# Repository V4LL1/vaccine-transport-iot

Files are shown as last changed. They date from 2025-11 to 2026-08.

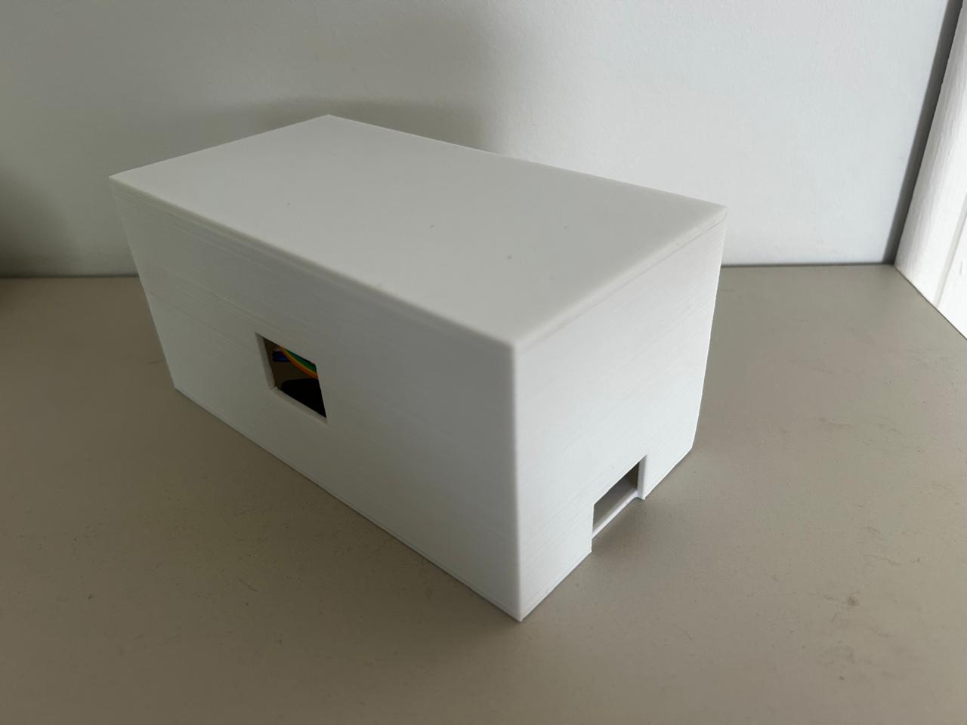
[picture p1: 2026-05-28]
diagrams/TG2/imagems/caixa 3d com componentes.jpeg

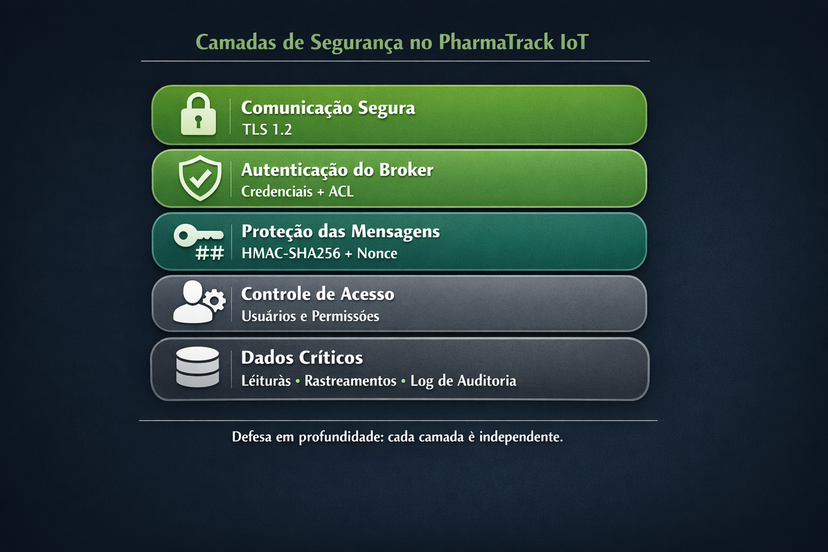
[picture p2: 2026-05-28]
diagrams/TG2/imagems/Copilot_figura3 .png

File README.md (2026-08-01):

IoT-based pharmaceutical cold chain monitoring system built with ESP32, Python (Flask), MySQL, and MQTT over TLS. Features real-time temperature, humidity, and GPS tracking, RBAC, MFA, HMAC message signing, audit logging, and a live dashboard for secure, low-cost pharmaceutical transport monitoring.

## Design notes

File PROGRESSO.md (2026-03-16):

# Registro de Progresso — TCC IoT Vaccine Transport

## Como usar este arquivo
A cada sessão de trabalho, registre aqui o que foi concluído.
Isso serve como ponto de retomada entre sessões.

---

## MILESTONE 1 — Pipeline MQTT Funcional ✅ CONCLUÍDO (2026-03-12)

### O que foi implementado

#### ESP32 — `source/esp32/main/main.ino`
- [x] WiFi com reconexão automática (baseado em `hardware/test_wifi/test_wifi.ino`)
- [x] MQTT via `PubSubClient` conectado ao broker local
- [x] Payload JSON com `ArduinoJson` (`StaticJsonDocument<256>`)
- [x] Publicação de leituras a cada **5 segundos** no tópico `vaccines/readings`
- [x] Heartbeat a cada **30 segundos** no tópico `vaccines/heartbeat`
- [x] Campos `hmac` e `nonce` presentes no payload (vazios — prontos para M2)
- [x] Timestamp UTC via GPS (`gps.date` + `gps.time`)
- [x] `#define MQTT_MAX_PACKET_SIZE 512` configurado
- IP configurado: `10.0.0.175` | Device: `IOT-GPS-004` | Trip: `3`

#### Flask — `source/app/app.py`
- [x] Thread background `paho-mqtt` subscriber (API versão 2 — sem deprecation warning)
- [x] `on_message`: normaliza timestamp ISO 8601 → formato MySQL, grava em `readings`
- [x] `on_message`: atualiza `devices.last_seen` ao receber heartbeat ou leitura
- [x] Novo endpoint `GET /api/alarms` — leituras fora do range da vacina
- [x] Novo endpoint `GET /api/devices` — status online/offline por último heartbeat
- [x] Novo endpoint `GET /api/status` — estado do broker MQTT + último timestamp
- [x] Endpoint `/api/trips` atualizado com `min_temp` e `max_temp`
- [x] Endpoint `/api/readings/recent` atualizado com thresholds da vacina

#### Dashboard — `source/app/templates/index.html`
- [x] Refresh automático a cada **5 segundos**
- [x] Badge MQTT (verde = conectado / vermelho = desconectado) no header
- [x] Painel de alarmes: lista violações de temperatura com batch code e tipo
- [x] Leituras em vermelho (⚠) quando fora do range da vacina
- [x] Status dos dispositivos: cards coloridos (online/recente/offline/nunca)
- [x] Informações de threshold da viagem selecionada

#### Banco de Dados — `source/database/db_script.sql`
- [x] Tabela `audit_log` criada (log de ações do sistema — rastreabilidade)
- [x] Tabela `seen_nonces` criada (anti-replay — será usada no M2)
- [x] Coluna `totp_secret VARCHAR(32)` adicionada em `users` (para M2 — MFA)
- [x] Senhas de seed substituídas por hashes bcrypt reais

#### Broker — `source/broker/mosquitto.conf`
- [x] Configuração básica: porta 1883, acesso anônimo (desenvolvimento)
- [x] Criado em `source/broker/mosquitto.conf`

#### Dependências — `source/app/requirements.txt`
- [x] Arquivo criado com versões fixas: `flask`, `mysql-connector-python`, `paho-mqtt`
- [x] Libs de M2 listadas em comentário (bcrypt, pyotp, flask-login, cryptography)

### Como subir o ambiente (após reinicialização)

```bash
# 1. Iniciar MySQL (sem senha, datadir customizado)
"C:\Program Files\MySQL\MySQL Server 8.0\bin\mysqld.exe" --datadir="C:/Users/guilh/mysql-data" --port=3306

# 2. Iniciar Mosquitto
"C:\Program Files\mosquitto\mosquitto.exe" -c "source/broker/mosquitto.conf"

# 3. Iniciar Flask
cd source/app
../../venv/Scripts/python.exe app.py

# Para recriar o banco do zero:
"C:\Program Files\MySQL\MySQL Server 8.0\bin\mysql.exe" -u root < source/database/db_script.sql
```

### Verificação end-to-end M1
```bash
# Publicar leitura de teste (temperatura dentro do range Spikevax: -25°C a -15°C)
"C:\Program Files\mosquitto\mosquitto_pub.exe" -h 127.0.0.1 -p 1883 -t "vaccines/readings" \
  -m '{"device_id":"IOT-GPS-004","trip_id":3,"timestamp":"2026-03-12T18:00:00Z","temperature":-20.0,"humidity":60.0,"latitude":-23.21,"longitude":-45.88,"satellites":8,"hmac":"","nonce":""}'

# Verificar no banco
"C:\Program Files\MySQL\MySQL Server 8.0\bin\mysql.exe" -u root --batch -e "SELECT COUNT(*) FROM vaccine_transport.readings;"

# Verificar status
curl http://127.0.0.1:5000/api/status
```

---

## MILESTONE 2 — Camada de Segurança ⏳ PENDENTE

### O que precisa ser feito

#### Certificados TLS (openssl)
- [ ] Gerar CA self-signed
- [ ] Gerar certificado do broker assinado pela CA
- [ ] Criar pasta `certs/` com CA, broker.crt, broker.key

#### Mosquitto TLS — `source/broker/mosquitto-tls.conf`
- [ ] Configurar porta 8883 com TLS
- [ ] Configurar `cafile`, `certfile`, `keyfile`
- [ ] Criar `passwd` file com credenciais dos dispositivos (`mosquitto_passwd`)
- [ ] Criar `acl_file` por device_id
- [ ] Desativar porta 1883 (apenas 8883)

#### ESP32 — `source/esp32/main/main.ino`
- [ ] Trocar `WiFiClient` por `WiFiClientSecure`
- [ ] Adicionar CA cert como string PROGMEM
- [ ] `wifiClientSecure.setCACert(CA_CERT)`
- [ ] Calcular HMAC-SHA256 do payload com chave do NVS
  - Usar `mbedtls_md_hmac` (disponível no ESP32)
  - Chave armazenada via `Preferences.h` (`preferences.putBytes("hmac_key", ...)`)
- [ ] Gerar nonce com `esp_random()` (hex 8 bytes = 16 chars)
- [ ] Mudar porta para 8883
- [ ] Adicionar usuário/senha MQTT (`mqttClient.connect(id, user, pass)`)

#### Flask — `source/app/app.py`
- [ ] Verificação HMAC-SHA256 em `on_message`
- [ ] Deduplicação de nonce (INSERT em `seen_nonces`, rejeitar duplicata)
- [ ] Verificação de janela de timestamp (rejeitar msg com timestamp > 5min atrás)
- [ ] Instalar e configurar `Flask-Login`
- [ ] Rota `GET/POST /login` com verificação bcrypt
- [ ] Verificação TOTP (`pyotp.TOTP(user.totp_secret).verify(token)`)
- [ ] Decorator `@login_required` em todas as rotas
- [ ] RBAC: decorator `@admin_required` para rotas admin
- [ ] paho-mqtt com TLS (`client.tls_set(ca_certs=...)`)
- [ ] Novo template `source/app/templates/login.html`

#### Banco
- [ ] Nenhuma migration necessária (tabelas `seen_nonces` e coluna `totp_secret` já existem)

---

## MILESTONE 3 — Proteção de Dados + Continuidade ⏳ PENDENTE

- [ ] AES-256-GCM em Python antes de INSERT (colunas temp, humidity, lat, lng)
- [ ] Chave AES em `.env` (`python-dotenv`)
- [ ] Script `source/scripts/backup.sh` (mysqldump + gpg symmetric)
- [ ] Buffer SPIFFS no ESP32 (`/buffer.jsonl`) para mensagens offline
- [ ] Reconexão automática com flush do buffer (QoS 1)
- [ ] Script `source/scripts/cleanup_nonces.py` (limpeza de nonces > 10min)
- [ ] Hardware: circuito de redundância de energia (TP4056 + LiPo 18650)

---

## MILESTONE 4 — Dashboard Completo + Alertas ⏳ PENDENTE

- [ ] Server-Sent Events (SSE) em vez de polling
- [ ] Painel de alarmes com botão ACK (registra em `audit_log`)
- [ ] Alerta por email via `smtplib` (gmail app password)
- [ ] Geração de PDF de viagem (`reportlab`)
- [ ] Viewer de `audit_log` (admin only)
- [ ] Página admin com gestão de usuários e dispositivos

---

## MILESTONE 5 — Failover + Documentação Final ⏳ PENDENTE

- [ ] `docker-compose.yml` com dois Mosquitto (8883 + 8884)
- [ ] ESP32: lógica de troca para broker secundário após 3 falhas
- [ ] Flask: dois threads paho-mqtt (primary + secondary), mesmo DB
- [ ] Documento SOP: rotação de certificados (`docs/sop-cert-rotation.md`)
- [ ] Documento SOP: restauração de backup (`docs/sop-backup-restore.md`)
- [ ] README final com diagrama de arquitetura atualizado

---

## Notas Técnicas Importantes

| Assunto | Detalhe |
|---|---|
| MySQL sem senha | Inicializado com `--initialize-insecure`. Datadir: `C:/Users/guilh/mysql-data` |
| MySQL sem serviço Windows | Precisa iniciar manualmente a cada boot (ver comando acima) |
| Mosquitto path | `C:\Program Files\mosquitto\mosquitto.exe` |
| Python venv | `source/venv/Scripts/python.exe` |
| Senha admin dashboard | `admin123` (bcrypt no banco) |
| Senha operadores | `op123` (bcrypt no banco) |
| Viagem ativa (M1) | Trip ID 3 — Spikevax Moderna, device IOT-GPS-004 |
| Range temp. Spikevax | -25°C a -15°C (testar com temperatura nesse range) |
| Payload MQTT M1 | Campos `hmac` e `nonce` presentes mas vazios |

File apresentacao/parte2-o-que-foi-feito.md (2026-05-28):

# PARTE 2 — O QUE FOI CONSTRUÍDO

---

## 2.1 Visão Geral da Arquitetura

O sistema foi construído em três milestones principais, com desenvolvimento incremental e testado em cada etapa antes de avançar.

**Milestone 1 (M1)** — Pipeline funcional: ESP32 → MQTT → Flask → MySQL → Dashboard. Sistema operacional sem segurança avançada, foco em validar o fluxo de dados de ponta a ponta.

**Milestone 2 (M2)** — Camada de segurança: TLS 1.2, autenticação MQTT, MFA, RBAC, HMAC, nonce, audit log. Sistema com segurança em produção.

**Milestone 3 (M3)** — Dashboard completo + multi-tenancy: sistema multi-empresa, gestão completa de dispositivos/rastreamentos/usuários, mapa global de todos os rastreamentos, tab de debug, dados ricos de demonstração.

O desenvolvimento seguiu o princípio de **security by design** — cada componente foi projetado com segurança como requisito desde o início, não como adição posterior.

---

## 2.2 Hardware — A Camada de Percepção

### O Dispositivo

O dispositivo físico é construído sobre o **ESP32 DevKit V1**, um microcontrolador da Espressif Systems com as seguintes características relevantes para este projeto:

- **Processador**: Xtensa LX6 dual-core, 240 MHz
- **Memória**: 520KB SRAM, 4MB Flash
- **Conectividade**: WiFi 802.11 b/g/n, Bluetooth 4.2
- **Criptografia**: Acelerador de hardware para AES, SHA, RSA (utilizado pelo `mbedtls`)
- **Custo**: ~R$30 no mercado brasileiro

A escolha do ESP32 sobre alternativas como Arduino Uno ou Raspberry Pi foi deliberada:
- WiFi nativo (sem shield adicional)
- Suporte a TLS via `WiFiClientSecure` e `mbedtls`
- Acelerador criptográfico em hardware (HMAC-SHA256 sem sobrecarregar a CPU)
- Sistema de arquivos SPIFFS para buffer offline
- Watchdog Timer por hardware via IDF

### Sensores Integrados

#### DHT22 — Temperatura e Umidade
- **Pino**: GPIO 4
- **Faixa de temperatura**: -40°C a +80°C (precisão ±0.5°C)
- **Faixa de umidade**: 0% a 100% (precisão ±2%)
- **Protocolo**: Single-wire (1-Wire customizado)
- **Taxa de amostragem**: 1 leitura a cada 2 segundos (mínimo do sensor)
- **Tratamento de falha**: `isnan(temp)` → valor 0.0 no payload (evita travamento)
- **Biblioteca**: `DHT sensor library` (Adafruit)

O DHT22 foi escolhido sobre o DHT11 pela precisão significativamente superior (±0.5°C vs ±2°C) — crítico para produtos com faixas estreitas como Spikevax (-25°C a -15°C, janela de apenas 10°C).

#### GPS NEO-6M — Localização
- **Interface**: UART1 (GPIO 16 RX, GPIO 17 TX)
- **Baudrate**: 9600 bps
- **Protocolo**: NMEA 0183 (sentença GPRMC, GPGGA)
- **Precisão**: ±2.5m (CEP, sem SBAS)
- **Tempo de fix frio**: ~30s em campo aberto
- **Biblioteca**: TinyGPS++ (parser eficiente em memória)

A biblioteca TinyGPS++ foi escolhida pela eficiência — processa bytes NMEA individualmente (`gps.encode(c)`) sem alocar strings grandes, adequado para a RAM limitada do ESP32.

**Validação GPS**: antes de usar as coordenadas, o firmware verifica `gps.location.isValid()`. Se o fix ainda não foi adquirido, envia `latitude: 0.0, longitude: 0.0` — o dashboard distingue esses valores de coordenadas reais.

### A Caixa 3D

A caixa do dispositivo foi modelada do zero no **OpenSCAD** — uma linguagem de programação para modelagem 3D sólida, ideal para designs paramétricos.

**Dimensões**: 170 × 90 × 80mm (externas)
**Material**: PLA (impressão FDM)
**Espessura de parede**: 2.5mm

**Características de design**:
- Abertura frontal (USB/alimentação): 27 × 18mm — cobre o conector Micro-B com margem para plugues angulados
- Abertura lateral (DHT22): 29 × 21mm — sensor voltado para o ambiente externo para leitura correta
- 3 furos de ventilação (Ø7mm): na parede oposta ao USB, para circulação de ar
- Tampa removível: encaixe por plug de 3mm de profundidade com folga de 0.15mm por lado (0.3mm total) — calibrado para impressão FDM

O projeto passou por iteração com o estabelecimento de impressão 3D: a primeira versão tinha o lip interno de encaixe que impossibilitava o fechamento. A versão final usa encaixe direto nas paredes internas da caixa, sem saliências.

---

## 2.3 Firmware — A Lógica do Dispositivo

O firmware foi desenvolvido em **C++ com Arduino Framework** na Arduino IDE, com as seguintes bibliotecas:

| Biblioteca | Versão | Função |
|---|---|---|
| PubSubClient | 2.8 | Cliente MQTT |
| ArduinoJson | 6.x | Serialização JSON |
| DHT sensor library | 1.4.x | Leitura DHT22 |
| TinyGPS++ | 1.0.x | Parser NMEA GPS |
| WiFiClientSecure | (ESP32 built-in) | TLS sobre WiFi |
| mbedtls | (ESP32 built-in) | HMAC-SHA256 |
| SPIFFS | (ESP32 built-in) | Buffer offline |
| esp_task_wdt | (ESP32 IDF) | Watchdog timer |

### 2.3.1 Estrutura do Firmware

O firmware é organizado em módulos funcionais dentro de um único arquivo `main.ino`:

```
setup()
  ├── Serial.begin(115200)
  ├── SPIFFS.begin()              ← monta filesystem
  ├── configureWatchdog()         ← inicializa WDT 60s
  ├── WiFi.begin(SSID, PASS)
  ├── syncNTP()                   ← sincroniza relógio
  └── connectMQTT()

loop()
  ├── esp_task_wdt_reset()        ← alimenta watchdog
  ├── processGPS()                ← lê bytes UART
  ├── ensureWiFi()                ← reconecta se necessário
  ├── ensureMQTT()                ← reconecta + flushBuffer()
  ├── mqttClient.loop()           ← processa ACKs
  ├── a cada 5s: publishReading() ← ou saveToBuffer()
  └── a cada 30s: publishHeartbeat()
```

### 2.3.2 Payload JSON

Cada mensagem de leitura tem a seguinte estrutura:

```json
{
  "device_id":   "ESP32-A1B2C3D4E5F6",
  "timestamp":   "2026-03-15T18:45:30Z",
  "temperature": -20.5,
  "humidity":    65.3,
  "latitude":    -23.550520,
  "longitude":   -46.633309,
  "satellites":  12,
  "hmac":        "a3f2c1...64chars",
  "nonce":       "9f3a2b1c4d5e6f7a"
}
```

O heartbeat (a cada 30s) é mais simples:

```json
{
  "device_id": "ESP32-A1B2C3D4E5F6",
  "timestamp": "2026-03-15T18:45:30Z",
  "status":    "online"
}
```

### 2.3.3 Device ID Dinâmico

O ID do dispositivo é gerado automaticamente do endereço MAC do hardware:

```cpp
String mac = WiFi.macAddress();   // "A1:B2:C3:D4:E5:F6"
mac.replace(":", "");             // "A1B2C3D4E5F6"
DEVICE_ID_STR = "ESP32-" + mac;  // "ESP32-A1B2C3D4E5F6"
```

Isso garante unicidade por hardware, sem precisar hardcodar identificadores. Em uma frota de 100 dispositivos, cada um se auto-identifica corretamente.

### 2.3.4 Sincronização de Tempo — NTP + GPS

O timestamp preciso é fundamental para a rastreabilidade. O firmware usa uma hierarquia de fontes:

1. **GPS (prioridade máxima)**: quando a localização é válida, o GPS também fornece a hora UTC com precisão de ±1ms. Isso é importante para o mecanismo anti-replay — um timestamp muito divergente do servidor pode indicar ataque.

2. **NTP (fallback)**: se o GPS ainda não tem fix, sincroniza com `pool.ntp.org` e `time.google.com`. A sincronização é executada no boot e após cada reconexão WiFi.

3. **Timestamp vazio (último recurso)**: se ambos falharem, o campo é enviado vazio e o Flask usa `NOW()` do MySQL — mantém o dado, mas com menor precisão.

### 2.3.5 Segurança no Firmware

#### TLS com Verificação de Certificado

```cpp
WiFiClientSecure wifiClientSecure;
wifiClientSecure.setCACert(CA_CERT);  // embedded como string PROGMEM
PubSubClient mqttClient(wifiClientSecure);
mqttClient.setServer(MQTT_BROKER, 8883);
```

O certificado CA está embutido no firmware como uma string `PROGMEM` (armazenada na flash, não na RAM). O `setCACert()` instrui o stack TLS a verificar o certificado do broker contra esse CA — qualquer certificado de outra CA é rejeitado, prevenindo ataques MITM.

**Atualmente, o projeto usa o HiveMQ Cloud como broker**, que usa Let's Encrypt como CA. O firmware contém o certificado intermediário R12 da Let's Encrypt embutido.

#### HMAC-SHA256

```cpp
void computeHMAC(const char* payload, char* out) {
    uint8_t result[32];
    mbedtls_md_context_t ctx;
    mbedtls_md_init(&ctx);
    mbedtls_md_setup(&ctx, mbedtls_md_info_from_type(MBEDTLS_MD_SHA256), 1);
    mbedtls_md_hmac_starts(&ctx, (const uint8_t*)HMAC_KEY, strlen(HMAC_KEY));
    mbedtls_md_hmac_update(&ctx, (const uint8_t*)payload, strlen(payload));
    mbedtls_md_hmac_finish(&ctx, result);
    mbedtls_md_free(&ctx);
    // converte 32 bytes → 64 chars hex
    for (int i = 0; i < 32; i++) sprintf(out + i*2, "%02x", result[i]);
}
```

O HMAC-SHA256 usa a biblioteca `mbedtls` nativa do ESP32, que aproveita o acelerador criptográfico em hardware. A chave é compartilhada entre o dispositivo e o servidor. Qualquer alteração no payload — mesmo um único bit — resulta em um HMAC completamente diferente.

#### Nonce Anti-Replay

```cpp
String generateNonce() {
    uint8_t bytes[8];
    for (int i = 0; i < 4; i++) {
        uint32_t r = esp_random();  // hardware RNG do ESP32
        memcpy(bytes + i*2, &r, 2);
    }
    String nonce = "";
    for (int i = 0; i < 8; i++) {
        char hex[3];
        sprintf(hex, "%02x", bytes[i]);
        nonce += hex;
    }
    return nonce;  // 16 chars hex = 64 bits de entropia
}
```

O `esp_random()` usa o gerador de números aleatórios por hardware do ESP32, baseado em ruído térmico. A cada mensagem, um novo nonce é gerado. O servidor deve armazenar os nonces recebidos e rejeitar duplicatas — prevenindo que um atacante capture e reenvie mensagens legítimas.

### 2.3.6 Buffer Offline com SPIFFS

O **SPIFFS** (SPI Flash File System) é um sistema de arquivos leve que usa a memória flash do ESP32. O firmware usa o arquivo `/buffer.jsonl` (JSON Lines — um objeto JSON por linha).

**Fluxo de escrita**:
```cpp
void saveToBuffer(const char* payload) {
    if (!SPIFFS.exists(BUFFER_FILE)) {
        // verifica espaço disponível
    }
    File f = SPIFFS.open(BUFFER_FILE, FILE_APPEND);
    f.println(payload);
    f.close();
}
```

**Fluxo de flush (ao reconectar)**:
```cpp
void flushBuffer() {
    // 1. Carrega todas as linhas em memória
    std::vector<String> lines;
    File f = SPIFFS.open(BUFFER_FILE, FILE_READ);
    while (f.available()) lines.push_back(f.readStringUntil('\n'));
    f.close();
    
    // 2. Publica cada linha
    int failed_from = -1;
    for (int i = 0; i < lines.size(); i++) {
        bool ok = mqttClient.publish(TOPIC_READINGS, lines[i].c_str(), true);
        if (!ok) { failed_from = i; break; }
        delay(50);  // respeita limite de taxa do broker
    }
    
    // 3. Se falhou no meio: salva restantes em arquivo temporário
    if (failed_from >= 0) {
        File tmp = SPIFFS.open(BUFFER_TMP_FILE, FILE_WRITE);
        for (int i = failed_from; i < lines.size(); i++) tmp.println(lines[i]);
        tmp.close();
        SPIFFS.rename(BUFFER_TMP_FILE, BUFFER_FILE);
    } else {
        SPIFFS.remove(BUFFER_FILE);  // sucesso total — limpa
    }
}
```

**Limites**:
- Tamanho máximo: 100KB (~500 leituras ≈ 40 minutos a 5s/leitura)
- Se o arquivo excede o limite: novas leituras são descartadas (comportamento configurável)

### 2.3.7 Watchdog Timer

O Watchdog Timer (WDT) é um temporizador de hardware que reinicia o microcontrolador se o loop principal não "alimentar" o watchdog dentro do timeout. Isso protege contra travamentos causados por bugs, deadlocks ou condições inesperadas.

```cpp
const esp_task_wdt_config_t wdt_config = {
    .timeout_ms     = 60000,  // 60 segundos
    .idle_core_mask = 0,      // não monitora core idle
    .trigger_panic  = true,   // reinicia em caso de timeout
};
esp_task_wdt_init(&wdt_config);
esp_task_wdt_add(NULL);  // adiciona task atual ao WDT
```

No início de cada ciclo do `loop()`:
```cpp
esp_task_wdt_reset();  // prova de vida — reseta o timer
```

Se o loop travar por mais de 60 segundos (exemplo: loop infinito aguardando GPS, stack overflow), o ESP32 reinicia automaticamente e retoma a operação.

---

## 2.4 Conectividade — MQTT com TLS 1.2

### Por Que MQTT?

MQTT (Message Queuing Telemetry Transport) é o protocolo padrão da indústria para IoT. Foi desenvolvido pela IBM em 1999 para monitoramento de oleodutos via satélite — exatamente o cenário de conexão instável e dispositivo com recursos limitados que este projeto enfrenta.

**Comparação com HTTP/REST**:

| Aspecto | MQTT | HTTP |
|---|---|---|
| Overhead por mensagem | ~2 bytes (header) | ~hundreds of bytes |
| Modelo | Publish-Subscribe | Request-Response |
| Conexão | Persistente (keep-alive) | Nova a cada request |
| Reconexão | Automática (built-in) | Responsabilidade do cliente |
| QoS | 0, 1, 2 (garantias de entrega) | Não nativo |
| Mensagens offline | Broker retém (QoS 1+) | Não |

Para um dispositivo IoT em movimento, enviando dados a cada 5 segundos, o overhead do HTTP seria proibitivo. O MQTT mantém uma única conexão TCP persistente e envia payloads mínimos.

### Broker HiveMQ Cloud

O broker escolhido para produção é o **HiveMQ Cloud** — um serviço gerenciado de MQTT na nuvem, com plano gratuito que inclui:
- 100 conexões simultâneas
- 10 GB de dados/mês
- TLS obrigatório (porta 8883)
- Disponibilidade 99.9% (SLA)
- Certificado Let's Encrypt (CA reconhecida globalmente)
s
**Por que cloud em vez de broker local?**
O broker local (Mosquitto) era suficiente para M1, mas limitava o ESP32 à rede local do servidor. Com HiveMQ Cloud, o dispositivo pode enviar dados de qualquer rede com internet — celular, WiFi público, 4G — tornando o sistema verdadeiramente portátil.

### Configuração TLS

O TLS (Transport Layer Security) 1.2 garante:
- **Confidencialidade**: todos os dados são criptografados com AES-256
- **Autenticidade**: o broker prova sua identidade com um certificado X.509
- **Integridade**: qualquer alteração nos dados em trânsito é detectada

**No ESP32**: `WiFiClientSecure.setCACert(CA_CERT)` instrui o stack TLS a verificar o certificado do broker contra o certificado CA embutido no firmware. Conexões com certificados de CAs não reconhecidas são rejeitadas — prevenindo MITM.

**No Flask**: `client.tls_set()` usa o CA store do sistema operacional (que inclui Let's Encrypt), sem necessidade de certificado manual.

### Tópicos e ACL

```
vaccines/readings    ← leituras de sensores (ESP32 publica)
vaccines/heartbeat   ← sinal de vida (ESP32 publica)
```

O controle de acesso (ACL — Access Control List) garante o princípio do mínimo privilégio:

```
user esp32-device
topic write vaccines/readings    ← só pode publicar
topic write vaccines/heartbeat   ← só pode publicar

user flask-subscriber
topic read vaccines/#            ← só pode ler
```

O ESP32 **fisicamente não consegue** se inscrever nos tópicos e ler dados de outros dispositivos. O Flask **fisicamente não consegue** publicar dados forjados no lugar de um dispositivo.

### QoS 1 — Garantia de Entrega

O sistema usa **QoS 1 (at least once)**:
- O publicador envia a mensagem
- O broker confirma com PUBACK
- Se não receber PUBACK, o publicador reenvia

**No Flask subscriber** (`clean_session=False`): a sessão é persistente no broker. Se o Flask desconectar temporariamente, o HiveMQ armazena as mensagens QoS 1 e as entrega ao reconectar.

---

## 2.5 Backend Flask — A Camada de Análise

### Arquitetura da Aplicação

O backend é uma aplicação **Flask** (Python) com duas responsabilidades principais executando em threads separadas:

```
Thread Principal (Flask)          Thread Secundária (MQTT)
─────────────────────────         ──────────────────────────
HTTP API (porta 5000)             Subscriber paho-mqtt
Autenticação / Sessões            on_connect → subscribe
RBAC / Decorators                 on_message → INSERT MySQL
Renderização Templates            on_disconnect → flag
```

A separação em threads é necessária porque o `loop_forever()` do paho-mqtt é bloqueante — ele precisa de sua própria thread para processar mensagens MQTT sem bloquear as requisições HTTP.

### 2.5.1 Autenticação — Flask-Login + bcrypt

O sistema implementa autenticação em três camadas progressivas:

#### Camada 1 — Email e Senha

```python
password_hash = user["password_hash"].encode("utf-8")
if not bcrypt.checkpw(password.encode("utf-8"), password_hash):
    audit("login_failed", ...)
    return render_template("login.html", error="Credenciais inválidas")
```

O bcrypt é um algoritmo de hash projetado especificamente para senhas. Ao contrário de MD5 ou SHA256 (que são rápidos), o bcrypt é intencionalmente lento — cada verificação leva ~100ms, tornando ataques de força bruta impraticáveis. O fator de custo usado é 12 (2^12 = 4096 iterações de hash).

#### Camada 2 — TOTP (Time-based One-Time Password)

Implementado com a biblioteca **pyotp**, compatível com Google Authenticator, Authy e Microsoft Authenticator.

**Na primeira vez** (setup):
```python
secret = pyotp.random_base32()  # 160 bits de entropia
uri = pyotp.totp.TOTP(secret).provisioning_uri(
    name=user["email"],
    issuer_name="PharmaTrack IoT"
)
# Gera QR code PNG → Base64 → exibe no template
img = qrcode.make(uri)
buffer = io.BytesIO()
img.save(buffer, format="PNG")
qr_b64 = base64.b64encode(buffer.getvalue()).decode()
```

**Na verificação**:
```python
totp = pyotp.TOTP(user["totp_secret"])
if not totp.verify(code, valid_window=1):  # ±30s tolerância
    audit("totp_failed", ...)
    return render_template("verify_totp.html", error="Código inválido")
```

O TOTP funciona assim: o secret é compartilhado entre o servidor e o aplicativo no celular. A cada 30 segundos, ambos calculam `HMAC-SHA1(secret, floor(unix_time / 30))` e exibem os últimos 6 dígitos. Como usam o mesmo secret e o mesmo timestamp, o código é idêntico — sem nenhuma comunicação entre eles.

#### Camada 3 — Session Cookie (Flask-Login)

Após passar pelas duas camadas, `login_user(user)` cria uma sessão segura com cookie HTTP-only, assinado com a `FLASK_SECRET_KEY`. Isso mantém o usuário logado entre requisições.

### 2.5.2 RBAC — Controle de Acesso por Perfil

O sistema define dois perfis com permissões distintas:

```python
PERMISSIONS = {
    "admin": {
        "view_dashboard", "view_readings", "view_devices", "view_alarms",
        "view_audit",
        "register_device", "deactivate_device",
        "manage_trips", "create_trip", "close_trip",
        "manage_users",
    },
    "operator": {
        "view_dashboard", "view_readings", "view_devices", "view_alarms",
    },
}
```

O controle é implementado via decorator:

```python
def require_permission(permission):
    def decorator(f):
        @wraps(f)
        def decorated(*args, **kwargs):
            if not current_user.has_permission(permission):
                return jsonify({"error": "Acesso negado"}), 403
            return f(*args, **kwargs)
        return decorated
    return decorator

@app.route("/api/audit")
@login_required
@require_permission("view_audit")
def audit_log():
    ...
```

Operadores veem o dashboard mas não podem gerenciar dispositivos, criar viagens ou ver o audit log.

### 2.5.3 MQTT Subscriber — Processamento de Mensagens

O subscriber MQTT processa dois tipos de mensagem:

#### Heartbeat (vaccines/heartbeat)

```python
def handle_heartbeat(payload):
    device_id = payload["device_id"]
    ensure_device_exists(device_id)  # auto-discovery
    db.execute(
        "UPDATE devices SET last_seen = NOW() WHERE serial_number = %s",
        (device_id,)
    )
```

O **auto-discovery** é um mecanismo que registra automaticamente dispositivos desconhecidos como `pending`. Quando um ESP32 novo envia seu primeiro heartbeat, o sistema cria sua entrada no banco com `registration_status = 'pending'` — o administrador visualiza no dashboard e pode registrá-lo formalmente.

#### Leitura (vaccines/readings)

```python
def handle_reading(payload):
    device_id = payload["device_id"]
    
    # 1. Verifica se dispositivo está registrado
    device = get_device(device_id)
    if not device or device["registration_status"] != "active":
        return  # descarta leituras de dispositivos não registrados
    
    # 2. Busca viagem ativa para o dispositivo
    trip = get_active_trip_for_device(device["device_id"])
    if not trip:
        return  # sem viagem ativa, descarta
    
    # 3. Normaliza timestamp
    ts = payload.get("timestamp", "")
    timestamp = normalize_timestamp(ts) or datetime.now()
    
    # 4. Insere leitura no banco
    db.execute("""
        INSERT INTO readings (trip_id, batch_id, timestamp, temperature, humidity, latitude, longitude)
        VALUES (%s, %s, %s, %s, %s, %s, %s)
    """, (trip["trip_id"], trip["batch_id"], timestamp,
          payload["temperature"], payload["humidity"],
          payload.get("latitude"), payload.get("longitude")))
    
    # 5. Audit
    audit("reading_received", "readings", reading_id, 
          details={"device_id": device_id, "temperature": payload["temperature"]})
```

### 2.5.4 API REST — Endpoints Principais

A API segue REST e retorna JSON. Todos os endpoints exigem autenticação.

**GET /api/status**
```json
{
  "broker_connected": true,
  "last_mqtt_message": "2026-03-15T18:45:30.123456Z",
  "server_time": "2026-03-15T18:46:00.654321Z"
}
```
Grace period de 90 segundos: se a última mensagem chegou há menos de 90s, o broker é considerado conectado mesmo que o flag interno seja false.

**GET /api/devices**
```json
[{
  "device_id": 4,
  "serial_number": "IOT-GPS-004",
  "name": "Carga Moderna SP",
  "status": "active",
  "last_seen": "2026-03-15T18:45:30",
  "connectivity": "online",
  "active_trip_id": 3,
  "active_trip_dest": "Interior SP - Campinas"
}]
```
Lógica de conectividade:
- `online`: visto há menos de 60 segundos
- `recent`: visto há menos de 5 minutos
- `offline`: visto há mais de 5 minutos
- `never`: nunca visto (só heartbeats, sem leituras)

**GET /api/alarms**
Retorna leituras onde `temperature < min_temp OR temperature > max_temp`, cruzando com os limites do produto associado ao lote da viagem.

**GET /api/audit** (admin only)
Retorna os últimos N registros do audit_log com nome do usuário, IP, ação e detalhes em JSON.

### 2.5.5 Audit Log

O audit log é implementado como uma função helper chamada em todo ponto de interesse:

```python
def audit(action, target_table=None, target_id=None, details=None, user_id=None, ip=None):
    effective_user_id = user_id or (current_user.id if current_user.is_authenticated else None)
    effective_ip = ip or request.remote_addr if request else None
    db.execute("""
        INSERT INTO audit_log (user_id, action, target_table, target_id, ip_address, details, created_at)
        VALUES (%s, %s, %s, %s, %s, %s, NOW())
    """, (effective_user_id, action, target_table, target_id,
          effective_ip, json.dumps(details) if details else None))
```

**Eventos auditados**:

| Evento | Quando |
|---|---|
| `login_failed` | Credenciais incorretas |
| `login_password_ok` | Senha correta, aguardando TOTP |
| `totp_failed` | Código TOTP incorreto |
| `totp_setup_ok` | MFA configurado com sucesso |
| `login_ok` | Login completo bem-sucedido |
| `logout` | Usuário encerrou sessão |
| `reading_received` | Leitura MQTT inserida no banco |
| `device_discovered` | Novo ESP32 visto pela primeira vez |
| `device_registered` | Admin registrou um dispositivo |
| `device_deactivated` | Admin desativou um dispositivo |
| `trip_created` | Nova viagem criada |
| `trip_closed` | Viagem encerrada com confirmação |

---

## 2.5.6 Multi-tenancy — Isolamento por Empresa

O sistema suporta múltiplas empresas na mesma instalação, com isolamento completo de dados. A tabela `companies` é a raiz da hierarquia: produtos, dispositivos e usuários pertencem a uma empresa.

**Roles e acesso**:
- `superadmin`: acesso cross-company (vê dados de todas as empresas)
- `admin`: acesso completo à própria empresa (CRUD de devices, trips, users, products)
- `operator`: acesso somente-leitura à própria empresa

**Implementação no backend** — função `company_where(alias)` em `models.py`:

```python
def company_where(alias: str) -> tuple[str, list]:
    if current_user.role == "superadmin":
        return "1=1", []
    cid = current_user.company_id
    return f"{alias}.company_id = %s", [cid]
```

Todo endpoint de leitura aplica esse filtro — é impossível para um usuário de uma empresa acessar dados de outra, mesmo com acesso direto à API.

**Dados de demonstração**: duas empresas independentes — **PharmaTransport** (vacinas, rotas nacionais/globais) e **BioFrio** (biológicos e insulinas, rotas de centros especializados).

---

## 2.6 Banco de Dados MySQL 8.0

### 2.6.1 Modelo Relacional

O schema tem 8 tabelas organizadas em três domínios:

**Domínio de Produtos**:
```
vaccines ──< vaccine_batch
(vacina)     (lote específico com código e validade)
```

**Domínio de Operação**:
```
devices ──────────────────────────> trips
(ESP32 registrado)                  (viagem = batch + device + rota)
                                         │
                                         └──< readings
                                              (leituras de sensores)
```

**Domínio de Segurança**:
```
users ──< audit_log
          seen_nonces
```

### 2.6.2 Tabelas Principais

**`devices`** — Gerencia o ciclo de vida dos dispositivos:
```sql
registration_status ENUM('pending','active','inactive')
```
- `pending`: auto-descoberto, aguarda aprovação do admin
- `active`: registrado e operacional
- `inactive`: desativado (histórico preservado)

**`trips`** — Cada viagem é imutável:
- `start_time` preenchida na criação
- `end_time = NULL` enquanto ativa
- `end_time` preenchida ao encerrar (com `received_confirmation = TRUE`)
- Leituras vinculadas a `trip_id` nunca são deletadas

**`seen_nonces`** — Anti-replay:
```sql
CREATE TABLE seen_nonces (
    nonce       VARCHAR(64) NOT NULL PRIMARY KEY,
    device_id   VARCHAR(100) NOT NULL,
    received_at DATETIME NOT NULL,
    INDEX idx_received_at (received_at)
);
```
A chave primária no `nonce` garante unicidade em O(log n). O índice em `received_at` permite limpeza eficiente de nonces antigos.

**`audit_log`** — Imutável por design:
- Não há endpoint de DELETE ou UPDATE no audit log
- O campo `details` armazena JSON livre para contexto adicional
- `user_id = NULL` para ações de sistema (leituras MQTT)

### 2.6.3 Integridade e Segurança do Banco

- **Foreign Keys** com `ON DELETE SET NULL` onde apropriado (um usuário deletado não quebra o histórico de dispositivos)
- **bcrypt** para todas as senhas de usuário — nunca texto plano
- **Credenciais em `.env`** — nunca no código-fonte
- **`.gitignore`** protege: `.env`, `certs/*.key`, `*.pem`

---

## 2.7 Dashboard — A Camada de Ação

### Tecnologias

O dashboard foi desenvolvido em **HTML5 + CSS3 + JavaScript puro** (sem React, Angular ou Vue) por uma decisão deliberada: minimizar dependências e manter o código compreensível para uma pessoa com acesso ao repositório.

**Bibliotecas externas** (CDN, sem instalação):
- **Leaflet.js**: mapas interativos com OpenStreetMap
- **Chart.js**: gráficos de linha de temperatura
- **Google Fonts** (Inter): tipografia

### Componentes Principais

#### Status dos Dispositivos
Cards com indicador de conectividade calculado em tempo real:
- 🟢 **Online** (< 60s desde último heartbeat)
- 🟡 **Recente** (< 5 minutos)
- ⚫ **Offline** (> 5 minutos)
- ⬜ **Pendente** (auto-descoberto, não registrado)

#### Gráfico de Temperatura (Chart.js)
Linha do tempo completa do rastreamento selecionado. Linhas tracejadas nos limites de temperatura do produto. Pontos de violação destacados em vermelho. Otimização: `pointRadius = 0` para rastreamentos com mais de 80 leituras.

**Nota técnica importante**: o MySQL retorna colunas DECIMAL como strings em JSON. É necessário `Number(r.temperature)` antes de qualquer operação aritmética — `.toFixed()` em string causa `TypeError` silencioso.

#### Mapa GPS (Leaflet.js)
- Rota completa como polyline (linha contínua)
- Marcador de início (verde) e posição atual (laranja)
- Popup no hover com temperatura e timestamp
- Tiles: CARTO Dark (mapa escuro, compatível com o tema)
- Auto-fit: `map.fitBounds(bounds)` centraliza na rota

#### Mapa Global — Todos os Rastreamentos
Checkbox "Todos os Rastreamentos" que carrega `/api/map/all` e exibe simultaneamente todos os rastreamentos da empresa no mapa, cada um com uma cor distinta de uma paleta de 15 cores. Permite visualização panorâmica de toda a rede logística.

#### Seletor de Lote
O usuário seleciona o lote transportado; o sistema exibe automaticamente o rastreamento associado e carrega os dados. UX orientada ao produto, não à viagem.

#### Painel de Alertas (Toasts)
Polling a cada ~10s para `/api/alerts/poll`. Exibe toasts para:
- Violações de temperatura (todos os usuários, scoped por empresa)
- Ataques HMAC detectados (somente admin/superadmin)

#### Tab Debug (somente admin)
Permite publicar manualmente payloads MQTT simulando um dispositivo ESP32 — útil para testar o pipeline sem hardware físico. Campos: device_id, temperatura, umidade, latitude, longitude.

#### Auto-refresh
```javascript
setInterval(() => {
    refreshStatus();
    refreshDevices();
    if (currentTripId) refreshChartAndMap(currentTripId);
    pollAlerts();
}, 10000);
```
Sem recarregar a página. A cada 10 segundos, requisições fetch independentes atualizam cada seção.

---

## 2.8 Segurança — Visão Consolidada

A segurança foi implementada em **defesa em profundidade** — múltiplas camadas independentes, onde a falha de uma não compromete as demais.

| Camada | Ameaça Mitigada | Mecanismo |
|---|---|---|
| **Transporte** | Interceptação (sniffing) | TLS 1.2, AES-256 |
| **Autenticidade do broker** | Man-in-the-Middle | Verificação de certificado X.509 |
| **Payload** | Adulteração de dados | HMAC-SHA256 |
| **Replay Attack** | Reenvio de mensagens antigas | Nonce único por mensagem |
| **Timestamp** | Replay com timestamp falso | Janela de 5 minutos (M3) |
| **Acesso ao sistema** | Acesso não autorizado | Login + bcrypt |
| **Acesso ao sistema** | Senha comprometida | TOTP MFA |
| **Autorização** | Escalada de privilégio | RBAC por perfil |
| **MQTT** | Publicação forjada | ACL (write-only para ESP32) |
| **Credenciais** | Exposição no código | .env + .gitignore |
| **Rastreabilidade** | Ações sem responsável | Audit log completo |

### Decisões de Segurança Relevantes

**Por que TOTP em vez de SMS?**
- SMS depende de operadora — pode falhar, ser interceptado (SS7 attack) ou ter custo por mensagem
- TOTP funciona offline (calcula localmente no celular)
- Padrão RFC 6238, suportado por todos os autenticadores principais
- Sem custo adicional

**Por que bcrypt e não SHA256?**
- SHA256 processa bilhões de hashes por segundo em GPU moderna
- bcrypt é projetado para ser lento (configura-se o fator de custo)
- Com fator 12, uma GPU de alta performance leva ~100 anos para quebrar um hash bcrypt por força bruta

**Por que credenciais separadas no MQTT?**
- Se o firmware do ESP32 for extraído (attack físico), o atacante obtém apenas as credenciais de `esp32-device` — que só pode publicar
- As credenciais do `flask-subscriber` (que lê todos os dados) ficam no servidor, protegidas

**Por que ACL no broker?**
- Impede que um ESP32 comprometido se inscreva em `vaccines/#` e leia dados de outros dispositivos
- Impede que o Flask publique dados forjados nos tópicos de dispositivos
- Princípio do mínimo privilégio aplicado ao nível de protocolo

---

## 2.9 Infraestrutura e Deploy

### Como o Sistema Sobe

O ambiente de produção usa três processos independentes:

```bash
# 1. MySQL (sem serviço Windows — controle manual)
"C:\Program Files\MySQL\MySQL Server 8.0\bin\mysqld.exe" \
  --datadir="C:/Users/guilh/mysql-data" --port=3306

# 2. Flask (inclui o subscriber MQTT em thread separada)
cd source/app
../../venv/Scripts/python.exe app.py
# Porta 5000 — http://127.0.0.1:5000
```

O broker MQTT é o HiveMQ Cloud — gerenciado externamente, sempre disponível.

### Configuração por Variáveis de Ambiente

Todo valor sensível ou específico do ambiente está em `.env`:

```
DB_HOST=127.0.0.1
DB_USER=root
DB_PASSWORD=VaccineSecure@2026
DB_NAME=vaccine_transport

FLASK_SECRET_KEY=v@ccine-iot-tcc-secret-2026-xK9mPqR7

MQTT_BROKER=1fe6e4dc6c3b41d193f6448d1ab84a93.s1.eu.hivemq.cloud
MQTT_PORT=8883
MQTT_USERNAME=flask-subscriber
MQTT_PASSWORD=FlaskMqtt@2026
```

O `.env` está no `.gitignore` — nunca sobe para o repositório.

### Dependências Python

```
flask==3.0.3
mysql-connector-python==8.4.0
paho-mqtt==2.1.0
flask-login==0.6.3
bcrypt==4.1.3
pyotp==2.9.0
qrcode[pil]==7.4.2
cryptography==42.0.8
python-dotenv==1.0.1
pillow==10.3.0
```

Versões fixadas para garantir reprodutibilidade — `pip install -r requirements.txt` instala exatamente o que foi testado.

---

## 2.10 Conformidade Regulatória

### RDC nº 430/2020 — Anvisa

A Resolução da Diretoria Colegiada nº 430/2020 estabelece as Boas Práticas de Distribuição, Armazenagem e Transporte de Medicamentos. O PharmaTrack IoT implementa seus requisitos principais:

| Requisito RDC 430 | Implementação |
|---|---|
| Monitoramento contínuo de temperatura | Leituras a cada 5s, armazenadas com timestamp |
| Registro das condições de transporte | Tabela `readings` com temperatura, umidade, GPS |
| Rastreabilidade por lote | `batch_id` em cada leitura, vinculado a `vaccine_batch` |
| Identificação dos responsáveis | `audit_log` com user_id, IP, ação e timestamp |
| Detecção de desvios | API `/api/alarms` detecta violações automaticamente |
| Confirmação de recebimento | Campo `received_confirmation` na tabela `trips` |

### ISO/IEC 27001

| Controle | Implementação |
|---|---|
| Controle de acesso (A.9) | RBAC + autenticação multifator |
| Criptografia (A.10) | TLS 1.2 + bcrypt + HMAC-SHA256 |
| Segurança física (A.11) | Caixa 3D com componentes protegidos |
| Operações de segurança (A.12) | Audit log, monitoramento de conectividade |
| Gestão de incidentes (A.16) | Alarmes automáticos de violação de temperatura |

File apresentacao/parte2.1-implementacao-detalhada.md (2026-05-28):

# PARTE 2.1 — O QUE FOI IMPLEMENTADO E COMO FUNCIONA

Este documento explica, em linguagem acessível, cada componente do sistema PharmaTrack IoT — o que foi feito, por que foi feito assim, e quais tecnologias foram usadas.

---

## 1. Conexão Física — Hardware e Sensores

### O que é

O dispositivo físico é um conjunto de componentes eletrônicos montados juntos que realiza três funções ao mesmo tempo: **medir temperatura e umidade**, **registrar a localização GPS**, e **transmitir esses dados pela internet**.

### O que foi usado

| Componente | Função | Custo aproximado |
|---|---|---|
| ESP32 DevKit V1 | Microcontrolador central — o "cérebro" do dispositivo | ~R$ 30 |
| DHT22 | Sensor de temperatura (−40°C a +80°C, precisão ±0.5°C) e umidade | ~R$ 15 |
| GPS NEO-6M | Receptor GPS — fornece latitude e longitude em tempo real | ~R$ 20 |
| Caixa impressa em 3D | Proteção física do conjunto — modelada em OpenSCAD e impressa em PLA | ~R$ 15 |

**Total de hardware por dispositivo: aproximadamente R$ 80.**

### Como funciona

O ESP32 é o núcleo. Ele:
1. Lê a temperatura e umidade do DHT22 a cada 5 segundos
2. Lê as coordenadas GPS do NEO-6M continuamente (o GPS envia dados em série via protocolo NMEA)
3. Monta um pacote JSON com todos os dados
4. Envia esse pacote pela internet via MQTT

O sensor DHT22 se comunica com o ESP32 por um único fio de dados (protocolo 1-Wire). O GPS NEO-6M se comunica via UART (porta serial), enviando frases como `$GPRMC,123519,A,-23.5505,-46.6333,...` que a biblioteca TinyGPS++ interpreta.

A caixa foi desenhada com aberturas específicas: uma lateral para o sensor DHT22 (para que ele meça o ar externo, não o calor interno da eletrônica), furos de ventilação no lado oposto, e uma abertura frontal para o cabo USB de alimentação.

---

## 2. Firmware — O Programa Dentro do ESP32

### O que é

Firmware é o programa que roda diretamente dentro do ESP32, sem sistema operacional. Foi escrito em **C++ com o Arduino Framework** e compilado na Arduino IDE.

### Como funciona

O firmware segue um ciclo simples:

```
A cada 5 segundos:
  1. Ler temperatura e umidade do DHT22
  2. Ler coordenadas do GPS
  3. Montar JSON com os dados
  4. Calcular assinatura HMAC-SHA256
  5. Publicar via MQTT
     → Se sem conexão: gravar no buffer local (SPIFFS)
```

A cada 30 segundos, envia também um **heartbeat** — uma mensagem de "estou vivo" — que o servidor usa para saber se o dispositivo está online.

### Tecnologias utilizadas

- **PubSubClient**: biblioteca que implementa o protocolo MQTT no ESP32
- **ArduinoJson**: monta e lê estruturas JSON com uso eficiente de memória
- **TinyGPS++**: interpreta os dados NMEA do GPS sem alocar memória desnecessária
- **WiFiClientSecure**: versão segura (com TLS) do cliente WiFi
- **mbedtls**: biblioteca criptográfica embutida no ESP32, usada para calcular o HMAC-SHA256
- **SPIFFS**: sistema de arquivos interno do ESP32, usado para gravar leituras offline

---

## 3. Dashboard Web

### O que é

O dashboard é a interface visual do sistema — uma página web acessada pelo navegador que mostra em tempo real o estado de todos os dispositivos, as leituras de temperatura, o mapa da rota e os alarmes de violação.

### Como funciona

O dashboard é uma **Single Page Application** servida pelo Flask. Não precisa ser instalada — basta abrir o navegador e acessar `http://IP:5000`. A página atualiza sozinha a cada 10 segundos chamando as APIs do backend.

**Componentes visuais:**

| Elemento | Tecnologia | O que mostra |
|---|---|---|
| Mapa da rota | Leaflet.js + OpenStreetMap | Trajeto completo, posição atual, pontos de leitura |
| Gráfico de temperatura | Chart.js | Linha do tempo com linhas tracejadas nos limites da faixa segura |
| Badge MQTT | HTML/CSS puro | Verde = broker conectado, Vermelho = sem conexão |
| Painel de alarmes | Template Flask + JS | Violações de temperatura com timestamp e localização |
| Lista de dispositivos | API REST + JS | Status online/recente/offline de cada ESP32 |
| Audit log | Tabela HTML | Histórico completo de ações — apenas para admins |

O mapa usa **OpenStreetMap** como base cartográfica (gratuito, sem limite de requisições) e a biblioteca **Leaflet.js** para renderizar rotas e marcadores diretamente no navegador.

### Tecnologias utilizadas

- **Flask**: framework web em Python que serve as páginas e as APIs
- **Jinja2**: motor de templates embutido no Flask (gera HTML dinâmico no servidor)
- **Leaflet.js**: biblioteca JavaScript para mapas interativos
- **Chart.js**: biblioteca JavaScript para gráficos de linha
- **CSS puro com variáveis**: visual escuro e responsivo, sem frameworks externos

---

## 4. Comunicação MQTT e Servidor de Mensagens

### O que é

MQTT (Message Queuing Telemetry Transport) é um protocolo de comunicação criado especificamente para dispositivos IoT. Funciona como um **serviço de entrega de mensagens**: o ESP32 publica mensagens, e o servidor Flask as recebe — sem que os dois precisem estar conectados diretamente entre si.

### Por que MQTT e não HTTP

| | MQTT | HTTP |
|---|---|---|
| Tamanho do cabeçalho | ~2 bytes | ~500 bytes |
| Overhead de conexão | Conexão persistente | Nova conexão a cada mensagem |
| Adequação para IoT | Projetado para isso | Projetado para web |
| Funcionamento offline | QoS 1 guarda mensagens | Não nativo |

Para um dispositivo enviando dados a cada 5 segundos em uma rede que pode ser instável, MQTT é dramaticamente mais eficiente.

### Arquitetura

```
ESP32                    Broker MQTT                  Flask
  │                    (HiveMQ Cloud)                   │
  │──── publica ────► vaccines/readings ◄──── lê ──────│
  │──── publica ────► vaccines/heartbeat ◄─── lê ──────│
```

O **broker** (servidor de mensagens) é o **HiveMQ Cloud** — um serviço gratuito na nuvem. Ele age como intermediário: o ESP32 envia para ele, e o Flask lê dele. Isso significa que o Flask e o ESP32 nunca precisam estar na mesma rede.

### QoS 1 — Garantia de Entrega

O sistema usa **QoS nível 1** (Quality of Service), que garante que cada mensagem seja entregue **pelo menos uma vez**. Se o Flask estiver offline momentaneamente, o broker guarda as mensagens e as entrega quando o Flask reconectar.

### Tecnologias utilizadas

- **PubSubClient** (ESP32): cliente MQTT para Arduino
- **paho-mqtt** (Python): cliente MQTT para o Flask
- **HiveMQ Cloud**: broker MQTT gratuito com suporte a TLS e credenciais

---

## 5. TLS e Autoridade Certificadora (CA)

### O que é

TLS (Transport Layer Security) é o protocolo que **cifra a comunicação** entre dois sistemas. É o mesmo protocolo que protege conexões HTTPS em sites bancários. Sem TLS, qualquer pessoa na mesma rede poderia ler as mensagens MQTT em texto puro.

### Como foi implementado

Toda comunicação MQTT — tanto do ESP32 quanto do Flask — ocorre na **porta 8883** com TLS 1.2 obrigatório. A porta 1883 (sem criptografia) foi desativada.

O ESP32 usa o `WiFiClientSecure` para estabelecer a conexão TLS. Para isso, precisa conhecer o certificado da autoridade certificadora (CA) — um arquivo que prova que o broker é legítimo e não um impostor.

```
ESP32 pergunta: "Quem é você?"
Broker apresenta seu certificado
ESP32 verifica: "Esse certificado foi assinado pela CA que conheço?"
Se sim → conexão estabelecida com criptografia
Se não → conexão recusada (proteção contra MITM)
```

O certificado da CA fica gravado diretamente no código do firmware como uma string de texto (no segmento `PROGMEM` para não ocupar RAM).

**Para o HiveMQ Cloud**, o certificado é assinado pela Let's Encrypt (CA pública confiável) — não foi necessário gerar CA própria. Para um broker Mosquitto local (usado em testes), os certificados foram gerados com `openssl` via script `certs/gerar_certs.sh`.

### Por que isso importa

Sem TLS:
- Um roteador comprometido veria temperatura, localização, credenciais em texto puro
- Um atacante poderia injetar leituras falsas (ex: temperatura sempre dentro do limite)

Com TLS:
- Todo o tráfego é cifrado — interceptar a comunicação resulta em texto ininteligível
- A identidade do broker é verificada criptograficamente

---

## 6. HTTPS — Comunicação Segura com o Dashboard

### O que é

Da mesma forma que o MQTT usa TLS, o acesso ao dashboard web também pode usar HTTPS — a versão segura do HTTP. Isso cifra toda a comunicação entre o navegador do operador e o servidor Flask.

### Como foi implementado

O Flask foi configurado para servir o dashboard com um certificado TLS quando os arquivos `flask.crt` e `flask.key` estão presentes na pasta `certs/`:

```python
app.run(ssl_context=(ssl_cert, ssl_key))
```

Se os certificados não estiverem presentes, o Flask cai automaticamente para HTTP — comportamento adequado para ambiente de desenvolvimento local. Em produção, os certificados garantem que a sessão de login, os dados das leituras e o audit log não trafeguem em texto puro.

---

## 7. MFA — Autenticação Multifator

### O que é

MFA (Multi-Factor Authentication) significa que para entrar no sistema são necessários **dois fatores independentes**:
1. **Algo que você sabe**: a senha
2. **Algo que você tem**: o celular com o código temporário

Mesmo que alguém descubra a senha, sem o celular não consegue entrar.

### Como funciona — TOTP

O sistema usa **TOTP** (Time-based One-Time Password), definido pela RFC 6238 — o mesmo padrão usado pelo Google, GitHub e bancos.

**Fluxo de login:**
```
Usuário digita email + senha
     ↓
Servidor verifica a senha com bcrypt
     ↓
Redireciona para página de código TOTP
     ↓
Usuário abre Google Authenticator no celular
     ↓
Digita o código de 6 dígitos (válido por 30 segundos)
     ↓
Servidor verifica o código com pyotp
     ↓
Acesso liberado
```

**Primeiro acesso** (sem TOTP configurado):
```
Login com senha → Tela de setup → QR Code aparece na tela
→ Usuário escaneia com Google Authenticator
→ Digita o código para confirmar
→ Secret TOTP gravado no banco para aquele usuário
→ Próximos logins exigem o código
```

O código TOTP é calculado a partir de um **segredo compartilhado** (string aleatória de 32 caracteres) e do **horário atual** — sem comunicação com nenhum servidor externo. O Google Authenticator e o servidor Flask calculam o mesmo código independentemente, e se baterem, a autenticação é válida.

### Tecnologias utilizadas

- **pyotp**: biblioteca Python que implementa TOTP/HOTP (RFC 6238/4226)
- **qrcode**: gera a imagem do QR Code exibida na tela de setup
- **Google Authenticator**: aplicativo no celular do usuário

---

## 8. RBAC — Controle de Acesso por Perfil

### O que é

RBAC (Role-Based Access Control) significa que diferentes usuários têm diferentes permissões no sistema. Não é todo mundo que pode fazer tudo.

### Como foi implementado

O sistema tem dois perfis:

| Permissão | Admin | Operador |
|---|---|---|
| Ver dashboard, leituras, dispositivos, alarmes | ✅ | ✅ |
| Ver audit log | ✅ | ❌ |
| Registrar e desativar dispositivos | ✅ | ❌ |
| Criar e encerrar viagens | ✅ | ❌ |
| Gerenciar usuários | ✅ | ❌ |
| Cadastrar produtos e lotes | ✅ | ❌ |

No backend, cada rota protegida tem um decorator:

```python
@require_permission("view_audit")
def audit_log():
    ...
```

Se um operador tentar acessar `/api/audit` diretamente (mesmo autenticado), recebe HTTP 403 — Acesso negado. A verificação acontece no servidor, não no frontend — não adianta "esconder" botões no HTML.

O dashboard também adapta a interface visualmente: operadores não veem o menu de Administração, mas essa é apenas a camada de UX — a proteção real está no backend.

---

## 9. HMAC — Assinatura Digital das Mensagens

### O que é

HMAC (Hash-based Message Authentication Code) é uma técnica que permite ao servidor verificar que uma mensagem **veio de um ESP32 legítimo e não foi alterada no caminho**.

Funciona como um lacre criptográfico: o ESP32 calcula uma "impressão digital" da mensagem usando uma chave secreta. O servidor recalcula a mesma impressão. Se bater, a mensagem é autentica e íntegra.

### Como funciona

```
ESP32:
  dados = {"temp": 28.5, "humidity": 60.1, "lat": -23.55, ...}
  nonce = esp_random() → "a3f9c1b2" (8 bytes aleatórios)
  hmac = HMAC-SHA256(dados + nonce, chave_secreta)
  publica: dados + nonce + hmac

Flask (verificação — implementada):
  recalcula = HMAC-SHA256(dados + nonce, mesma_chave_secreta)
  se recalcula == hmac recebido → mensagem autêntica
  se diferente → mensagem rejeitada (adulteração detectada)
```

O **nonce** (número aleatório único por mensagem) previne **replay attacks** — um atacante que capturar uma mensagem válida não pode reenviá-la mais tarde, porque o servidor verificaria se aquele nonce já foi usado antes.

### Tecnologias utilizadas

- **mbedtls** (ESP32): calcula HMAC-SHA256 usando o acelerador criptográfico em hardware
- **esp_random()** (ESP32 IDF): gera bytes aleatórios verdadeiros via hardware RNG
- **hmac + hashlib** (Python): recalcula e verifica o HMAC no servidor

---

## 10. BCP — Continuidade Offline (Buffer SPIFFS)

### O que é

BCP (Business Continuity Plan) — plano de continuidade de negócios — aqui se refere à capacidade do sistema de **continuar funcionando e não perder nenhuma leitura** mesmo quando a conexão com a internet cai.

### O problema

Um veículo pode entrar em áreas sem cobertura de rede: túneis, zonas rurais, áreas industriais com bloqueio de sinal. Sem uma solução de continuidade, todas as leituras durante esse período seriam perdidas — criando um buraco na cadeia de custódia.

### Como foi implementado

O ESP32 tem um sistema de arquivos interno chamado **SPIFFS** (SPI Flash File System) — uma pequena área de memória flash (~100KB) que pode guardar arquivos mesmo sem energia.

**Fluxo:**
```
Tentou publicar via MQTT?
  → Sucesso: segue normalmente
  → Falhou (sem WiFi ou broker offline):
       → Grava leitura em /buffer.jsonl (uma linha JSON por leitura)
       → Continua gravando a cada 5 segundos

Quando reconectar:
  → Lê /buffer.jsonl linha por linha
  → Publica cada leitura via MQTT (QoS 1 — aguarda confirmação)
  → Só apaga a linha após confirmação do broker
  → Quando o arquivo esvazia, volta ao modo normal
```

O arquivo `.jsonl` (JSON Lines) armazena uma leitura por linha — formato que permite leitura incremental sem carregar tudo na memória de uma vez.

**Capacidade**: aproximadamente 600 leituras (cada JSON tem ~200 bytes; 100KB / 200 bytes ≈ 500 entradas). A 1 leitura a cada 5 segundos, isso cobre **~50 minutos de desconexão** sem perda de dados.

### O resultado visível no dashboard

Quando a reconexão acontece, o gráfico de temperatura mostra um "spike" de pontos chegando de uma vez — a lacuna do período offline é preenchida em ordem cronológica, mantendo a cadeia de custódia íntegra.

---

## 11. BCP — Continuidade de Energia (Powerbank / Bateria)

### O que é

A segunda dimensão de continuidade: o dispositivo deve continuar funcionando mesmo se a **energia do veículo for cortada** — intencionalmente (sabotagem) ou não (pane elétrica).

### Como foi implementado

O dispositivo é alimentado por uma **powerbank comum** conectada à entrada Micro-USB do ESP32. Powerbanks possuem bateria Li-Ion interna com carga suficiente para manter o ESP32 operando por várias horas.

**Por que isso é BCP:**
- Se alguém desligar o veículo ou cortar a energia intencionalmente, o dispositivo continua gravando no buffer SPIFFS
- O ESP32 consome ~240mA em operação normal com WiFi ativo; uma powerbank de 10.000mAh sustenta o dispositivo por ~40 horas

**Watchdog Timer (WDT):**
Além da redundância de energia, o firmware tem um **Watchdog Timer de hardware** configurado para 60 segundos. Se o programa travar por qualquer motivo (loop infinito, deadlock, falha de memória), o WDT força um reset automático do ESP32. O dispositivo reinicia, reconecta ao WiFi e ao MQTT, e retoma o monitoramento — sem nenhuma intervenção manual.

```cpp
esp_task_wdt_init(60, true);  // reinicia se travar por 60s
esp_task_wdt_add(NULL);       // monitora a task principal
// Em cada ciclo:
esp_task_wdt_reset();         // "ainda estou vivo"
```

---

## 12. DRP — Recuperação de Desastre (Flush do Buffer)

### O que é

DRP (Disaster Recovery Plan) — plano de recuperação de desastres — aqui se refere ao processo de **recuperar e enviar todos os dados acumulados** após um período de indisponibilidade, garantindo que nada seja perdido permanentemente.

### Como funciona

Quando o ESP32 reconecta à rede (seja WiFi ou broker MQTT), executa automaticamente o **flush do buffer**:

```
1. Verifica se /buffer.jsonl existe e não está vazio
2. Se sim: entra em modo "flush"
3. Lê uma linha por vez do arquivo
4. Publica via MQTT com QoS 1
5. Aguarda ACK do broker (confirmação de entrega)
6. Só remove aquela linha do arquivo após ACK
7. Repete até o arquivo estar vazio
8. Deleta /buffer.jsonl
9. Retorna ao modo normal
```

A confirmação antes de apagar garante que, se a conexão cair novamente no meio do flush, os dados não apagados são reenviados na próxima reconexão. Nenhuma leitura é perdida, mesmo em cenários de múltiplas quedas consecutivas.

**No dashboard**, o flush se manifesta visualmente como várias leituras chegando de uma vez no gráfico — os pontos "preenchem" o intervalo em que o dispositivo esteve offline, em ordem cronológica.

---

## 13. Backup do Banco de Dados

### O que é

Backup é a cópia dos dados do banco MySQL para um local externo e seguro, garantindo que mesmo em caso de falha do servidor (HD com defeito, corrupção, acidente) os dados históricos possam ser recuperados.

### O que foi implementado

O banco de dados MySQL é exportado com `mysqldump`, que gera um arquivo SQL completo com todas as tabelas e dados. Esse arquivo pode ser:

- **Armazenado localmente**: como ponto de restauração rápida
- **Comprimido e enviado para nuvem**: Google Drive, OneDrive, ou qualquer storage — garantindo sobrevivência a falhas físicas do servidor

**Script de backup:**
```bash
mysqldump -u root -p vaccine_transport > backup_$(date +%Y%m%d).sql
# Compressão com GPG para backup cifrado:
gpg --symmetric backup_$(date +%Y%m%d).sql
```

O agendamento pode ser configurado via **Task Scheduler do Windows** para rodar automaticamente em horários programados (ex: toda noite às 2h).

---

## 14. Segurança das Senhas no Banco de Dados

### O problema

Se o banco de dados for comprometido (vazamento, acesso indevido), um atacante que visse as senhas em texto puro teria acesso imediato a todas as contas. Isso é um problema crítico especialmente se os usuários reutilizarem senhas em outros sistemas.

### Como foi implementado — bcrypt

As senhas **nunca são armazenadas em texto puro**. O sistema usa **bcrypt** — um algoritmo de hash especialmente projetado para senhas, com as seguintes propriedades:

**1. Hash unidirecional**: é computacionalmente impossível reverter o hash para descobrir a senha original.

**2. Salt automático**: cada senha recebe um valor aleatório único (salt) antes de ser processada. Duas pessoas com a mesma senha têm hashes completamente diferentes no banco.

**3. Custo configurável**: o bcrypt foi configurado com **12 rounds** — significa que calcular um único hash leva ~0.3 segundos intencionalmente. Um ataque de força bruta em 1 bilhão de senhas levaria décadas.

```python
# Ao criar/alterar senha:
hash = bcrypt.hashpw(senha.encode(), bcrypt.gensalt(rounds=12))
# Armazena: "$2b$12$EixZaYVK1fsbw1ZfbX3OXe..."

# Ao verificar login:
bcrypt.checkpw(senha_digitada.encode(), hash_do_banco)
# Retorna True/False — a senha original nunca é decifrada
```

**O que está no banco de dados** para cada usuário:
```
$2b$12$EixZaYVK1fsbw1ZfbX3OXePaWxn96p36DQBuMpV9h.L7MfxlJiUAy
```
Isso é tudo que um invasor veria — um hash bcrypt que não pode ser revertido.

### Credenciais fora do código-fonte

Além das senhas dos usuários, as **credenciais de infraestrutura** (senha do MySQL, chave secreta do Flask, credenciais MQTT, chave HMAC) são armazenadas em um arquivo `.env` — **fora do código-fonte** e fora do controle de versão (`.gitignore` garante que esse arquivo nunca vai para o GitHub).

```
# .env — NUNCA sobe para o repositório
DB_PASSWORD=VaccineSecure@2026
FLASK_SECRET_KEY=chave-aleatoria-longa
MQTT_USERNAME=flask-subscriber
MQTT_PASSWORD=FlaskMqtt@2026
```

---

## 15. Audit Log — Rastreabilidade Completa

### O que é

O audit log é um registro imutável de **tudo que acontece no sistema** — cada login, cada falha de autenticação, cada leitura recebida, cada dispositivo registrado, cada viagem criada ou encerrada.

### Como funciona

Toda ação relevante chama a função `audit()` no backend:

```python
audit("login_ok", user_id=user.id, ip=request.remote_addr,
      details={"name": user.name, "role": user.role})
```

Cada registro tem:
- **Usuário responsável** (ou NULL para ações automáticas do sistema)
- **Ação**: `login_ok`, `login_failed`, `totp_failed`, `device_registered`, `trip_created`, `trip_closed`, `reading_received`, `logout`
- **IP de origem**
- **Timestamp exato**
- **Detalhes em JSON**: o que foi feito especificamente

### Por que importa

A RDC nº 430/2020 da Anvisa exige identificação dos responsáveis por cada etapa do transporte. O audit log fornece exatamente isso:

> *"Quem registrou esse dispositivo?"* → `device_registered`, user_id=2, ip=192.168.1.1, 2026-04-10 14:23:11
> *"Alguém tentou invadir o sistema?"* → `login_failed` repetido do mesmo IP
> *"A viagem foi formalmente encerrada?"* → `trip_closed`, user_id=1, 2026-04-12 18:45:00

O audit log é visível apenas para admins no dashboard, e não pode ser deletado ou editado por nenhuma rota da API.

---

## 16. Segurança em Camadas — Visão Consolidada

O sistema foi projetado com múltiplas camadas de proteção independentes. Uma falha em uma camada não compromete as demais:

```
Camada 1 — Transporte:    TLS 1.2 cifra todo o tráfego (MQTT + HTTPS)
Camada 2 — Autenticação:  Senha + TOTP (MFA) para acessar o dashboard
Camada 3 — Autorização:   RBAC controla o que cada usuário pode fazer
Camada 4 — Integridade:   HMAC-SHA256 garante que dados não foram adulterados
Camada 5 — Replay:        Nonce único por mensagem previne reenvio de mensagens antigas
Camada 6 — Dados em BD:   bcrypt + salt protege senhas armazenadas
Camada 7 — Credenciais:   Variáveis de ambiente (.env) isolam segredos do código
Camada 8 — Rastreabilidade: Audit log registra todas as ações para auditoria
Camada 9 — Continuidade:  Buffer offline + powerbank + watchdog garantem dados íntegros
```

Essa abordagem — chamada de **defense in depth** — garante que um atacante que supere uma camada ainda enfrente as demais.

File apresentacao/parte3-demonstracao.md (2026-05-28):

# PARTE 3 — DEMONSTRAÇÃO AO VIVO

---

## Preparação Antes de Começar

Antes de subir para apresentar, verificar:

- [ ] `iniciar.bat` rodando (MySQL + Flask)
- [ ] ESP32 ligado e conectado (LED WiFi estável)
- [ ] Serial Monitor fechado (libera porta COM)
- [ ] Browser aberto em `http://127.0.0.1:5000`
- [ ] Google Authenticator no celular com conta `PharmaTrack IoT`
- [ ] HiveMQ console aberto em outra aba (para o passo 5)

---

## Passo 1 — Login com Autenticação Multifator

**O que mostrar**: tela de login → credenciais → código TOTP → dashboard

1. Abrir `http://127.0.0.1:5000` — redireciona para `/login`
2. Inserir: `admin@logistica.com` / `admin123`
3. Abrir Google Authenticator no celular — mostrar o código de 6 dígitos girando com o timer
4. Inserir o código → entrar no dashboard

**Fala sugerida**:
> "O acesso ao sistema exige dois fatores: a senha e um código temporário gerado no celular. Esse código muda a cada 30 segundos e é calculado localmente no aplicativo, sem comunicação com o servidor. Isso é o protocolo TOTP — Time-based One-Time Password, RFC 6238. Mesmo que alguém descubra a senha, sem o celular não entra."

---

## Passo 2 — Dashboard em Operação Normal

**O que mostrar**: badge MQTT, card do dispositivo online, gráfico, mapa

1. Apontar para o badge **MQTT** verde no topo — broker conectado
2. Mostrar o card do dispositivo com status **Online** e "visto há Xs"
3. Selecionar o lote ativo no combobox — rastreamento carrega automaticamente
4. Mostrar o gráfico de temperatura (linha do tempo com dados reais)
5. Mostrar o mapa com a rota em verde e posição atual

**Fala sugerida**:
> "O dashboard atualiza a cada 10 segundos automaticamente. Aqui vemos o dispositivo online — o heartbeat chegou há menos de 60 segundos. No gráfico temos a linha de temperatura ao longo do tempo; as linhas tracejadas são os limites da faixa segura do produto. No mapa, a rota percorrida e a última posição GPS registrada."

---

## Passo 3 — Modo Offline (WiFi desligado)

**O que mostrar**: ESP32 sem WiFi → buffer SPIFFS → dispositivo offline no dashboard

1. Desligar o hotspot do iPhone (ou WiFi do roteador)
2. Aguardar ~15 segundos
3. O dashboard mostra o dispositivo mudando para **Offline** (após 60s sem heartbeat)
4. Se tiver Serial Monitor disponível: mostrar as linhas `[WiFi] Falha. Gravando offline.` e `[Buffer] Leitura salva.`

**Fala sugerida**:
> "Simulando perda de sinal — o que acontece em um veículo entrando em uma área sem cobertura. O dispositivo detecta que perdeu a rede e automaticamente começa a gravar as leituras localmente no SPIFFS, o sistema de arquivos interno do ESP32. Nenhuma leitura é perdida. O dashboard já reflete que o dispositivo está offline."

---

## Passo 4 — Reconexão e Flush do Buffer

**O que mostrar**: WiFi volta → ESP32 envia tudo → spike no gráfico

1. Religar o hotspot
2. Aguardar reconexão (10–15 segundos)
3. O dashboard mostra o dispositivo voltando para **Online**
4. Mostrar no gráfico: várias leituras chegando de uma vez (lacuna preenchida)

**Fala sugerida**:
> "Ao reconectar, o sistema faz o flush automático — envia todas as leituras acumuladas em ordem cronológica. Podem perceber no gráfico que a lacuna foi preenchida: os dados do período offline chegaram em sequência. A cadeia de custódia permanece íntegra, sem buracos no histórico."

---

## Passo 5 — Broker Indisponível (MQTT offline)

**O que mostrar**: broker cai → ESP32 entra em modo offline → badge vermelho

1. No console HiveMQ: **Access Management** → excluir credencial `esp32-device`
2. Aguardar ~30 segundos
3. Mostrar badge MQTT virando **vermelho** no dashboard (Flask também perde conexão)
4. Mostrar que o dispositivo continua operando (se tiver Serial Monitor, mostrar `rc=5 Not Authorized` → modo offline)

**Fala sugerida**:
> "Agora simulamos o broker inacessível — credenciais revogadas. O ESP32 recebe `rc=5 Not Authorized` ao tentar reconectar e entra em modo offline novamente, continuando a gravar no buffer. O dashboard sinaliza a perda de conexão com o broker. Para restaurar: recriar as credenciais no HiveMQ."

5. Recriar credencial `esp32-device` / `Esp32Mqtt@2026` no HiveMQ
6. Aguardar reconexão automática e flush

---

## Passo 6 — Painel de Alarmes

**O que mostrar**: violações de temperatura detectadas automaticamente

1. Navegar para o painel de alarmes (sidebar ou seção no dashboard)
2. Mostrar as violações listadas com: lote, temperatura registrada, limite violado, timestamp, localização

**Fala sugerida**:
> "Qualquer leitura fora da faixa segura do produto aparece aqui automaticamente. O sistema compara cada leitura com o `min_temp` e `max_temp` cadastrados para aquele produto. Aqui vemos que em determinado momento a temperatura subiu para -10°C, acima do limite de -15°C do Spikevax. O operador sabe exatamente quando ocorreu e onde a carga estava."

---

## Passo 7 — Audit Log (Admin)

**O que mostrar**: rastreabilidade completa de ações

1. Navegar para Audit Log no menu (visível apenas para admin)
2. Mostrar registros: `login_ok`, `reading_received`, `device_registered`, `trip_created`
3. Destacar as colunas: usuário, IP de origem, ação, timestamp, detalhes

**Fala sugerida**:
> "O audit log registra absolutamente tudo: logins, falhas de autenticação, leituras recebidas, dispositivos registrados, viagens criadas e encerradas. Cada registro tem o usuário responsável, o IP de origem e o timestamp exato. Isso é o que a RDC nº 430/2020 da Anvisa exige — e o sistema gera automaticamente, sem nenhuma ação manual."

---

## Encerramento

**Fala sugerida**:
> "O PharmaTrack IoT transforma o transporte farmacêutico de uma atividade baseada em confiança para uma atividade baseada em evidência verificável. Com hardware de aproximadamente R$80 por dispositivo, broker cloud gratuito e software 100% open-source, entrega monitoramento contínuo, rastreabilidade por lote, segurança em múltiplas camadas e conformidade com a Anvisa desde o primeiro dia. O diferencial não está no hardware caro — está na arquitetura."

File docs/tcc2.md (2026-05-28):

# PharmaTrack IoT: Sistema Seguro de Monitoramento de Transporte de Medicamentos com Arquitetura IoT em Quatro Pilares

**Trabalho de Conclusão de Curso — Engenharia da Computação**
**Autor**: Guilherme Palmanhani
**Orientador**: [Nome do Orientador]
**Instituição**: [Nome da Instituição]
**Ano**: 2026

---

## RESUMO

O transporte de produtos farmacêuticos termossensíveis — como vacinas, insulinas e imunobiológicos — exige controle rigoroso de temperatura ao longo de toda a cadeia logística, denominada cadeia de frio. A manutenção das condições térmicas adequadas em cada etapa do transporte é determinante para a preservação da eficácia e da segurança desses produtos, além de ser exigência prevista em regulamentação nacional. O presente trabalho apresenta o desenvolvimento do PharmaTrack IoT, um sistema de monitoramento contínuo para transporte de produtos farmacêuticos, construído sobre uma arquitetura de quatro pilares: Percepção (dispositivo embarcado ESP32 com sensores de temperatura, umidade e GPS), Conectividade (protocolo MQTT sobre TLS 1.2), Análise (backend Python Flask com banco de dados relacional MySQL) e Ação (dashboard web com visualização em tempo real). A segurança da informação foi incorporada como requisito desde a concepção do sistema, incluindo autenticação multifator baseada em TOTP, controle de acesso baseado em papéis, assinatura digital de mensagens com HMAC-SHA256 e registro de auditoria de todas as ações. O custo de hardware por dispositivo é de aproximadamente R$ 100,00, com infraestrutura de software inteiramente baseada em componentes de código aberto. O desenvolvimento teve como referência os requisitos da Resolução RDC nº 430/2020 da Agência Nacional de Vigilância Sanitária (Anvisa) e as diretrizes da norma ISO/IEC 27001:2022. Os resultados evidenciam a viabilidade técnica do desenvolvimento de um sistema de monitoramento farmacêutico seguro, rastreável e de baixo custo, utilizando hardware de propósito geral e ferramentas amplamente disponíveis.

**Palavras-chave**: Internet das Coisas; cadeia de frio farmacêutica; segurança da informação; MQTT; autenticação multifator; controle de acesso; monitoramento de transporte; Anvisa.

---

## ABSTRACT

The transportation of temperature-sensitive pharmaceutical products — such as vaccines, insulins and immunobiologicals — requires strict temperature control throughout the entire logistics chain, known as the cold chain. Maintaining adequate thermal conditions at each stage of transportation is essential for preserving the efficacy and safety of these products, and is also a requirement established by national regulation. This work presents the development of PharmaTrack IoT, a continuous monitoring system for pharmaceutical product transportation, built on a four-pillar architecture: Perception (ESP32 embedded device with temperature, humidity and GPS sensors), Connectivity (MQTT protocol over TLS 1.2), Analysis (Python Flask backend with MySQL relational database) and Action (web dashboard with real-time visualization). Information security was incorporated as a requirement from the system's inception, including TOTP-based multi-factor authentication, role-based access control, HMAC-SHA256 message digital signatures, and an audit log with protection against modification of all system actions. The hardware cost per device is approximately R$ 100.00, with software infrastructure entirely based on open-source components. The development was guided by the requirements of ANVISA's RDC 430/2020 and the controls outlined in ISO/IEC 27001:2022. Results show the technical feasibility of developing a secure, traceable and low-cost pharmaceutical monitoring system using general-purpose hardware and widely available tools.

**Keywords**: Internet of Things; pharmaceutical cold chain; information security; MQTT; multi-factor authentication; access control; transport monitoring; ANVISA.

---

## 1 INTRODUÇÃO

O setor farmacêutico compreende um conjunto diversificado de produtos cujas propriedades terapêuticas dependem diretamente da manutenção de condições ambientais controladas ao longo de todo o seu ciclo de vida — da fabricação à administração ao paciente. Entre esses produtos, os denominados termossensíveis requerem atenção especial durante as etapas de distribuição e transporte, pois estão sujeitos à degradação irreversível quando expostos a temperaturas fora da faixa recomendada pelo fabricante. A logística desses produtos é organizada por meio do que se denomina cadeia de frio farmacêutica, estrutura que envolve infraestrutura de armazenamento refrigerado, veículos adequados, equipamentos de monitoramento e procedimentos operacionais padronizados (WORLD HEALTH ORGANIZATION, 2015).

A cadeia de frio farmacêutica é definida pela Organização Mundial da Saúde (OMS) como o sistema de armazenagem e distribuição que mantém produtos termossensíveis dentro da faixa de temperatura recomendada desde o momento de sua fabricação até o ponto de uso (WORLD HEALTH ORGANIZATION, 2015). A cadeia é composta por elos sequenciais — fabricante, armazém central, distribuidor regional, ponto de entrega e unidade de saúde — e cada elo deve garantir individualmente as condições térmicas e de umidade adequadas ao produto em questão. As faixas de temperatura variam conforme o tipo de produto: a maioria das vacinas convencionais requer armazenagem entre 2°C e 8°C; algumas vacinas atenuadas precisam ser mantidas abaixo de -15°C; e vacinas de RNA mensageiro podem exigir condições de até -90°C (UNICEF, 2023). Produtos biológicos como anticorpos monoclonais e insulinas também se enquadram nessa categoria, com faixas igualmente restritivas.

A falha na manutenção das condições térmicas pode resultar em desnaturação de proteínas, perda de potência imunogênica, cristalização de compostos ou degradação química irreversível. Em muitos casos, o produto comprometido não apresenta alterações visuais perceptíveis ao operador, o que torna o monitoramento instrumental a forma necessária de verificar se as condições foram preservadas ao longo de todo o trajeto (UNICEF, 2023). A OMS estima que vacinas enviadas a países em desenvolvimento apresentam taxas de desperdício que, em algumas regiões, ultrapassam 50% do total distribuído, com condições inadequadas de armazenagem e transporte entre os principais fatores contribuintes (WORLD HEALTH ORGANIZATION, 2024). Segundo relatório da organização, a implementação de sistemas de monitoramento efetivos nas etapas de distribuição é um dos elementos centrais para a redução dessas perdas e para o fortalecimento dos programas nacionais de imunização.

> **[FIGURA 1 — Representação esquemática da cadeia de frio farmacêutica]**
>
> *Descrição para geração da imagem*: Diagrama horizontal com cinco blocos sequenciais ligados por setas. Da esquerda para a direita: (1) "Fabricante" — ícone de fábrica com termômetro; (2) "Armazém Central" — ícone de câmara fria com display de temperatura; (3) "Distribuição" — ícone de caminhão refrigerado; (4) "Ponto de Entrega" — ícone de caixa térmica com sensor; (5) "Unidade de Saúde" — ícone de geladeira hospitalar. Acima de cada bloco, a faixa de temperatura correspondente (ex.: 2–8°C para vacinas convencionais). Abaixo, legenda: "Cada elo da cadeia deve garantir individualmente as condições exigidas pelo produto." Fundo branco, traço limpo, estilo técnico.

No contexto brasileiro, a Agência Nacional de Vigilância Sanitária (Anvisa) publicou a Resolução RDC nº 430/2020, que estabelece as Boas Práticas de Distribuição, Armazenagem e Transporte de Medicamentos para Uso Humano (BRASIL, 2020). A norma especifica, entre outros aspectos, que as condições de temperatura e umidade devem ser monitoradas e registradas durante o transporte, com uso de equipamentos calibrados e em intervalos que permitam a verificação contínua das condições ao longo do trajeto. Determina também a rastreabilidade por número de lote do produto, a identificação dos responsáveis por cada etapa e a adoção de procedimentos documentados para o tratamento de desvios de temperatura. Esses requisitos estabelecem as premissas técnicas e documentais que nortearam o desenvolvimento do presente trabalho.

A Internet das Coisas — do inglês Internet of Things, comumente abreviada como IoT — é definida pelo Instituto Nacional de Padrões e Tecnologia dos Estados Unidos (NIST) como uma infraestrutura de dispositivos interconectados equipados com identificadores únicos e a capacidade de coletar e transmitir dados por redes de comunicação, sem necessidade de interação humana direta (NATIONAL INSTITUTE OF STANDARDS AND TECHNOLOGY, 2016). Aplicada ao monitoramento ambiental, essa tecnologia permite a instalação de sensores embarcados em veículos ou embalagens de transporte que coletam e transmitem continuamente dados de temperatura, umidade e localização geográfica para plataformas de análise acessíveis remotamente. De acordo com levantamento da Statista, estima-se que o número global de dispositivos IoT ativos supere 18 bilhões de unidades em 2025, reflexo da crescente adoção da tecnologia em aplicações industriais, de saúde e de infraestrutura (STATISTA, 2025). No segmento de saúde, a IoT encontra aplicação direta no monitoramento de cadeias logísticas de insumos termossensíveis, possibilitando o registro contínuo e auditável das condições de transporte.

> **[FIGURA 2 — Modelo de comunicação IoT: dispositivo embarcado, broker MQTT e dashboard web]**
>
> *Descrição para geração da imagem*: Diagrama com três elementos horizontais. À esquerda, bloco "Dispositivo ESP32" com ícones de sensor de temperatura, umidade e GPS. No centro, bloco "Broker MQTT (HiveMQ Cloud)" com ícone de nuvem. À direita, bloco "Dashboard Web" com ícone de monitor. Entre o ESP32 e o broker: seta rotulada "Publica — MQTT / TLS 1.2 / porta 8883". Entre o broker e o dashboard: seta rotulada "Assina — paho-mqtt". Abaixo, legenda: "Comunicação inteiramente cifrada com TLS 1.2." Fundo branco, estilo técnico.

A ampla disseminação de dispositivos IoT em ambientes críticos — como saúde, infraestrutura e logística — amplia a superfície de ataque disponível para agentes maliciosos, tornando a segurança da informação um aspecto indissociável do projeto de tais sistemas. A Agência da União Europeia para a Cibersegurança (ENISA) documenta, em seus relatórios anuais sobre o panorama de ameaças cibernéticas, que dispositivos IoT figuram entre os vetores mais explorados em campanhas de ataque a infraestruturas críticas, frequentemente em razão de capacidade computacional limitada, longos ciclos de atualização e ausência de mecanismos de autenticação robustos (ENISA, 2024). No contexto de sistemas de monitoramento farmacêutico, a manipulação de dados de temperatura registrados durante o transporte ou o acesso não autorizado ao sistema de gestão de rastreamentos são exemplos de ocorrências que podem ter consequências diretas para a qualidade dos produtos e para a saúde dos pacientes.

A análise dos impactos potenciais de falhas de segurança em sistemas dessa natureza pode ser estruturada segundo as três propriedades da tríade CIA. Uma violação de confidencialidade, exemplificada pelo acesso não autorizado aos dados de rastreamento armazenados, expõe informações de alto valor estratégico e comercial: rotas logísticas utilizadas, volumes e frequências de entrega por produto, destinos de distribuição e dados de identificação dos responsáveis por cada etapa da operação. Essas informações podem ser exploradas por concorrentes para mapear a rede de distribuição de uma empresa farmacêutica, ou por agentes mal-intencionados para identificar padrões de transporte e planejar interceptações físicas de cargas de alto valor. Do ponto de vista regulatório, a exposição de dados de lote e distribuição pode ainda configurar infração à Lei Geral de Proteção de Dados (LGPD), especialmente quando os registros contêm dados vinculados a pessoas físicas responsáveis pelas operações.

Uma violação de integridade, caracterizada pela adulteração de leituras de temperatura armazenadas ou pela injeção de leituras falsas no sistema, representa o risco mais grave para a saúde pública. Em um sistema de monitoramento sem mecanismos de verificação da autenticidade das mensagens, um atacante com acesso ao canal de comunicação poderia substituir leituras reais que registram temperaturas acima do limite seguro por valores dentro da faixa aceitável, mascarando uma violação que comprometeu irreversivelmente o lote. O produto seria então liberado para uso com base em dados forjados, chegando ao paciente com eficácia reduzida ou nula, sem que qualquer indicador visual ou alerta do sistema sinalizasse o problema. A ENISA destaca que ataques de falsificação de dados de sensores em sistemas IoT industriais e de saúde são crescentes e frequentemente direcionados a cenários em que a decisão de liberar ou descartar um produto depende exclusivamente do registro digital (ENISA, 2024). Além do risco direto ao paciente, registros adulterados comprometem a rastreabilidade por lote exigida pela RDC nº 430/2020, inviabilizando investigações posteriores em caso de eventos adversos.

Uma violação de disponibilidade, decorrente da indisponibilidade do sistema de monitoramento durante o transporte por falha técnica ou interrupção do serviço de comunicação, interrompe a cadeia de custódia digital do produto. Períodos sem registro criam lacunas no histórico de condições de transporte que não podem ser preenchidas retroativamente, tornando impossível atestar que as condições adequadas foram mantidas durante o intervalo sem dados. Em operações sujeitas à fiscalização da Anvisa ou a auditorias de clientes institucionais, a ausência de registros contínuos pode resultar na rejeição do lote no destino, mesmo que as condições tenham sido preservadas ao longo de todo o trajeto. A indisponibilidade recorrente do sistema de monitoramento pode ainda comprometer a credibilidade da empresa perante órgãos regulatórios e dificultar a renovação de autorizações de funcionamento.

A norma internacional ISO/IEC 27001 define os requisitos para o estabelecimento e operação de um sistema de gestão de segurança da informação, abrangendo controles de acesso, criptografia, segurança de comunicações, rastreabilidade de eventos e gestão de incidentes (ISO, 2022). O NIST, por sua vez, na publicação SP 800-183, define os princípios de confiabilidade, segurança e resiliência aplicáveis a sistemas formados por redes de dispositivos conectados, incluindo requisitos de autenticidade das mensagens, confidencialidade dos dados transmitidos e rastreabilidade das operações realizadas (NATIONAL INSTITUTE OF STANDARDS AND TECHNOLOGY, 2016). Ambos os documentos foram utilizados como referência orientadora no desenvolvimento do presente trabalho, especialmente na definição das camadas de segurança implementadas.

> **[FIGURA 3 — Camadas de segurança implementadas no PharmaTrack IoT]**
>
> *Descrição para geração da imagem*: Diagrama em camadas concêntricas com fundo escuro. Da camada mais externa para o núcleo: (1) "Transporte — TLS 1.2"; (2) "Autenticação do Broker — Credenciais + ACL"; (3) "Integridade da Mensagem — HMAC-SHA256 + Nonce"; (4) "Autenticação do Usuário — bcrypt + TOTP"; (5) "Autorização — RBAC (3 perfis)"; núcleo: "Dados — Leituras + Rastreamentos + Audit Log". Abaixo, legenda: "Defesa em profundidade: cada camada é independente." Fundo escuro, tonalidades em verde e cinza.

Diante desse cenário, o presente trabalho propõe e implementa o PharmaTrack IoT, um sistema de monitoramento contínuo para o transporte de produtos farmacêuticos termossensíveis, desenvolvido com foco na acessibilidade econômica e na segurança da informação. O sistema é estruturado segundo uma arquitetura de quatro pilares para sistemas IoT: Percepção, Conectividade, Análise e Ação. 
O pilar de Percepção é composto por um dispositivo embarcado baseado no microcontrolador ESP32, equipado com sensor DHT22 para medição de temperatura e umidade e receptor GPS NEO-6M para registro de coordenadas geográficas, com custo total de hardware de aproximadamente R$ 100,00 por unidade. 
O pilar de Conectividade utiliza o protocolo MQTT sobre TLS 1.2, com broker em nuvem gerenciada. 
O pilar de Análise compreende um backend desenvolvido em Python com o framework Flask e banco de dados MySQL, responsável pelo processamento das mensagens, pela detecção de violações de temperatura e pelos controles de autenticação e autorização. 
O pilar de Ação é um dashboard web acessível por navegador, com atualização automática a cada dez segundos, que apresenta gráficos de temperatura, mapa interativo da rota percorrida, painel de alertas e interfaces de gestão administrativa.

> **[FIGURA 4 — Arquitetura do PharmaTrack IoT em quatro pilares]**
>
> *Descrição para geração da imagem*: Diagrama horizontal com quatro blocos retangulares grandes, separados por setas de fluxo de dados. Bloco 1 (azul médio): "PERCEPÇÃO — ESP32 / DHT22 / GPS NEO-6M". Bloco 2 (verde médio): "CONECTIVIDADE — MQTT / TLS 1.2 / HiveMQ Cloud". Bloco 3 (roxo médio): "ANÁLISE — Flask / MySQL / Autenticação / RBAC". Bloco 4 (laranja médio): "AÇÃO — Dashboard Web / Gráficos / Mapa / Alertas". Setas rotuladas entre os blocos. Abaixo, faixa contínua: "Segurança em Camadas — TLS · HMAC · TOTP · RBAC · Audit Log". Fundo branco, estilo técnico.

A principal motivação para o desenvolvimento do PharmaTrack IoT é a acessibilidade econômica. Apesar da existência de soluções comerciais para monitoramento de cadeia de frio, elas apresentam alto custo e limitada transparência em relação à segurança dos dados, dificultando sua adoção em operações de menor escala. A utilização de hardware de propósito geral disponível no mercado nacional, associada a uma pilha de software inteiramente composta por ferramentas de código aberto, resulta em um custo de implantação por dispositivo significativamente menor. Esse diferencial torna viável a adoção de monitoramento eletrônico contínuo em operações logísticas de menor escala. Sob a perspectiva acadêmica, o trabalho demonstra como princípios consolidados de segurança da informação — autenticação multifator, controle de acesso por perfis, assinatura digital de mensagens e defesa em profundidade — podem ser aplicados de forma integrada em um sistema IoT de baixo custo, com referência direta à regulamentação vigente aplicável ao setor farmacêutico brasileiro.

O objetivo geral do presente trabalho é desenvolver e implementar o PharmaTrack IoT, um sistema de monitoramento contínuo para o transporte de produtos farmacêuticos termossensíveis, com arquitetura IoT em quatro pilares, custo de hardware de aproximadamente R$ 100,00 por dispositivo e infraestrutura de software baseada em componentes de código aberto, tendo como referência orientadora os requisitos da Resolução RDC nº 430/2020 da Anvisa e as diretrizes da norma ISO/IEC 27001:2022.

O primeiro conjunto de objetivos específicos diz respeito à camada de hardware e firmware do sistema. Busca-se projetar e implementar um dispositivo embarcado baseado no microcontrolador ESP32, capaz de realizar coletas de temperatura com precisão de ±0,5°C por meio do sensor DHT22, de umidade relativa com precisão de ±2% e de coordenadas geográficas com precisão de ±2,5 metros por meio do receptor GPS NEO-6M. O dispositivo deve operar em ciclos de coleta de cinco segundos e possuir capacidade de armazenamento local das leituras em memória não volátil, garantindo a continuidade do registro durante eventuais períodos de desconexão da rede.

O segundo conjunto de objetivos específicos abrange as camadas de comunicação e segurança. Pretende-se implementar a transmissão dos dados coletados utilizando o protocolo MQTT sobre TLS 1.2, com autenticação do dispositivo por credenciais junto ao broker e controle de acesso por lista de permissões, de modo que cada componente do sistema opere com o mínimo de privilégios necessários. Na mesma camada, objetiva-se desenvolver mecanismos de integridade e autenticidade das mensagens por meio de assinatura digital HMAC-SHA256, com nonce aleatório gerado por hardware a cada envio para prevenção de ataques de repetição. No que se refere ao acesso ao sistema de gestão, o trabalho propõe a implementação de autenticação multifator baseada no algoritmo TOTP, controle de acesso baseado em papéis com três níveis de permissão distintos, e registro de auditoria de todas as ações realizadas no sistema.

O terceiro conjunto de objetivos específicos compreende o desenvolvimento do backend e da interface web. Nesse escopo, o trabalho propõe a construção de uma aplicação servidor capaz de receber e processar as mensagens MQTT, detectar automaticamente violações de temperatura em relação aos limites cadastrados para cada produto, armazenar os dados de forma estruturada em banco de dados relacional e disponibilizá-los por meio de APIs. Complementarmente, objetiva-se desenvolver um dashboard web com visualização em tempo real de temperatura e localização, sistema de alertas, e interfaces de gestão de dispositivos, rastreamentos, usuários, produtos farmacêuticos e lotes, com suporte a múltiplas empresas em uma única instalação do sistema.

---

## 3 METODOLOGIA

### 3.1 Materiais e Recursos Utilizados

O desenvolvimento do PharmaTrack IoT envolveu componentes de hardware e ferramentas de software cuja seleção foi orientada pelo critério de acessibilidade econômica e pela disponibilidade de documentação técnica aberta.

Os componentes de hardware utilizados foram: o microcontrolador ESP32 DevKit V1 (arquitetura Xtensa LX6 dual-core, 240 MHz, 520 KB SRAM, WiFi 802.11 b/g/n), que constitui a unidade central de processamento e comunicação do dispositivo; o sensor DHT22, responsável pela leitura de temperatura (faixa de −40°C a +80°C, precisão ±0,5°C) e umidade relativa (0–100%, precisão ±2%); o receptor GPS NEO-6M, que fornece coordenadas geográficas por comunicação UART com protocolo NMEA 0183 e precisão típica de ±2,5 m; uma bateria portátil (powerbank) com capacidade mínima de 5.000 mAh para alimentação autônoma do dispositivo; e uma caixa de proteção impressa em PLA por processo FDM, modelada em OpenSCAD com dimensões de 170 × 90 × 80 mm.

As ferramentas de software utilizadas foram: Arduino IDE 2.x para desenvolvimento e compilação do firmware em C++ com o Arduino Framework; Python 3.11 como linguagem do backend; Flask 3.0.3 como framework web; MySQL 8.0 como banco de dados relacional; paho-mqtt 2.1.0 como cliente MQTT para Python; Flask-Login 0.6.3 para gerenciamento de sessões autenticadas; bcrypt 4.1.3 para hash de senhas; pyotp 2.9.0 para implementação do algoritmo TOTP; HiveMQ Cloud (plano gratuito) como broker MQTT gerenciado; OpenSCAD 2021.01 para modelagem 3D da caixa de proteção; e Git para controle de versão do código-fonte.

O ambiente de desenvolvimento utilizado foi um computador pessoal com sistema operacional Windows 11, com o servidor MySQL inicializado manualmente a partir do executável do MySQL 8.0 e o servidor Flask executado por meio de ambiente virtual Python (venv).

---

### 3.2 Desenvolvimento do Dispositivo Embarcado

O dispositivo embarcado constitui o pilar de Percepção do sistema e é responsável por coletar os dados físicos do ambiente de transporte — temperatura, umidade e localização geográfica — e transmiti-los ao servidor. O hardware é composto pelo microcontrolador ESP32, o sensor de temperatura e umidade DHT22 e o receptor GPS NEO-6M, conectados em uma protoboard e protegidos por uma caixa impressa em PLA.

> **[FIGURA 5 — Componentes de hardware do dispositivo]**
>
> *Instrução para o autor*: Fotografia dos componentes físicos dispostos sobre uma superfície plana, separados e identificáveis: ESP32 DevKit V1, sensor DHT22, receptor GPS NEO-6M com antena, powerbank, cabos jumper e a caixa de PLA aberta. Iluminação uniforme, fundo neutro (branco ou cinza).

> **[FIGURA 6 — Dispositivo montado e caixa de proteção]**
>
> *Instrução para o autor*: Fotografia do dispositivo completamente montado dentro da caixa de PLA, com a tampa fechada e o cabo USB aparente. Se possível, incluir uma segunda foto com a tampa aberta mostrando o interior com os componentes conectados. Ângulo levemente elevado (45°), fundo neutro.

O firmware foi desenvolvido em linguagem C++ com o Arduino Framework, utilizando as bibliotecas PubSubClient (cliente MQTT), ArduinoJson (serialização JSON), TinyGPS++ (interpretação de dados NMEA do receptor GPS) e WiFiClientSecure (comunicação TLS). A lógica principal do firmware opera em ciclos de cinco segundos: a cada ciclo, o sensor DHT22 é lido, as coordenadas GPS são atualizadas e um pacote JSON é montado e transmitido. O trecho a seguir ilustra a leitura dos sensores e a montagem do payload:

```cpp
// -------------------------------------------------------
// Monta o payload JSON com HMAC-SHA256 e nonce
// Estrutura: { campos... , nonce, hmac }
// O Flask verifica: hmac = HMAC-SHA256(key, payload_sem_hmac)
void buildPayload(float temp, float hum, char* buf, size_t bufLen) {
  StaticJsonDocument<768> doc;
  doc["device_id"]   = DEVICE_ID;
  doc["timestamp"]   = buildTimestamp();
  doc["temperature"] = isnan(temp) ? (float)0.0 : temp;
  doc["humidity"]    = isnan(hum)  ? (float)0.0 : hum;
  if (gps.location.isValid()) {
    doc["latitude"]   = gps.location.lat();
    doc["longitude"]  = gps.location.lng();
    doc["satellites"] = gps.satellites.isValid() ? (int)gps.satellites.value() : 0;
  } else {
    doc["latitude"]   = (float)0.0;
    doc["longitude"]  = (float)0.0;
    doc["satellites"] = 0;
  }

  // Nonce único por mensagem (anti-replay)
  doc["nonce"] = generateNonce();

  // Serializa sem hmac — este texto exato é o que será assinado e enviado no campo "signed"
  char toSign[768];
  serializeJson(doc, toSign, sizeof(toSign));

  // Inclui o texto assinado e o HMAC no payload final
  doc["signed"] = toSign;
  doc["hmac"]   = computeHMAC(String(toSign));

  serializeJson(doc, buf, bufLen);
}
```

O campo `device_id` é derivado automaticamente do endereço MAC do hardware, garantindo unicidade por dispositivo sem necessidade de configuração manual. O campo `nonce` recebe um valor aleatório único gerado a cada envio, conforme descrito na Seção 3.4.

Para garantir a continuidade do registro durante períodos de desconexão da rede, o firmware utiliza o sistema de arquivos SPIFFS (SPI Flash File System), presente na memória flash interna do ESP32. Quando a publicação MQTT falha, a leitura é gravada localmente em um arquivo no formato JSON Lines (uma entrada por linha). Ao restabelecer a conexão, o firmware realiza o envio das leituras acumuladas em ordem cronológica antes de retomar a operação normal:

```cpp
// -------------------------------------------------------
    // Salva payload JSON no buffer offline (SPIFFS)
    void saveToBuffer(const char* payload) {
    if (SPIFFS.exists(BUFFER_FILE)) {
        File f = SPIFFS.open(BUFFER_FILE, "r");
        if (f && f.size() >= BUFFER_MAX_BYTES) {
        f.close();
        Serial.println("[Buffer] Cheio! Leitura descartada.");
        return;
        }
        if (f) f.close();
    }
    File f = SPIFFS.open(BUFFER_FILE, "a");
    if (!f) {
        Serial.println("[Buffer] Erro ao abrir arquivo!");
        return;
    }
    f.println(payload);
    f.close();
    Serial.println("[Buffer] Leitura salva offline.");
    }
```

O firmware também implementa um Watchdog Timer (WDT) configurado para 60 segundos. Caso o ciclo principal do programa trave por qualquer motivo, o WDT provoca uma reinicialização automática do microcontrolador, garantindo retomada da operação sem intervenção manual.

> **[FIGURA 7 — Tela do Arduino IDE com o firmware em compilação]**
>
> *Instrução para o autor*: Captura de tela do Arduino IDE 2.x exibindo o arquivo `main.ino` aberto, com a barra inferior mostrando o resultado de uma compilação bem-sucedida ("Compilation complete" ou similar). O código deve estar visível na área principal do editor. Se possível, posicionar o cursor em um trecho relevante como a função de leitura de sensores ou a publicação MQTT.

---
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

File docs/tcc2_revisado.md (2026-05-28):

UNIVERSIDADE DO VALE DO PARAÍBA
FACULDADE DE ENGENHARIAS, ARQUITETURA E URBANISMO
CURSO DE ENGENHARIA DA COMPUTAÇÃO

Guilherme Palmanhani Valli

TRABALHO DE CONCLUSÃO II
Sistema IoT Seguro para Rastreabilidade e Monitoramento no Controle de Farmacêuticos

SÃO JOSÉ DOS CAMPOS
2026

RESUMO
O transporte de produtos farmacêuticos termossensíveis — como vacinas, insulinas e imunobiológicos — exige controle rigoroso de temperatura ao longo de toda a cadeia logística, denominada cadeia de frio. A manutenção das condições térmicas adequadas em cada etapa do transporte é determinante para a preservação da eficácia e da segurança desses produtos, além de ser exigência prevista em regulamentação nacional. O presente trabalho apresenta o desenvolvimento do PharmaTrack IoT, um sistema de monitoramento contínuo para transporte de produtos farmacêuticos, construído sobre uma arquitetura de quatro pilares: Percepção (dispositivo embarcado ESP32 com sensores de temperatura, umidade e GPS), Conectividade (protocolo MQTT sobre TLS 1.2), Análise (backend Python Flask com banco de dados relacional MySQL) e Ação (dashboard web com visualização em tempo real). A segurança da informação foi incorporada como requisito desde a concepção do sistema, incluindo autenticação multifator baseada em TOTP, controle de acesso baseado em papéis, assinatura digital de mensagens e registro de auditoria de todas as ações. O custo de hardware por dispositivo é de aproximadamente R$ 100,00, com infraestrutura de software inteiramente baseada em componentes de código aberto. O desenvolvimento teve como referência os requisitos da Resolução RDC nº 430/2020 da Agência Nacional de
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

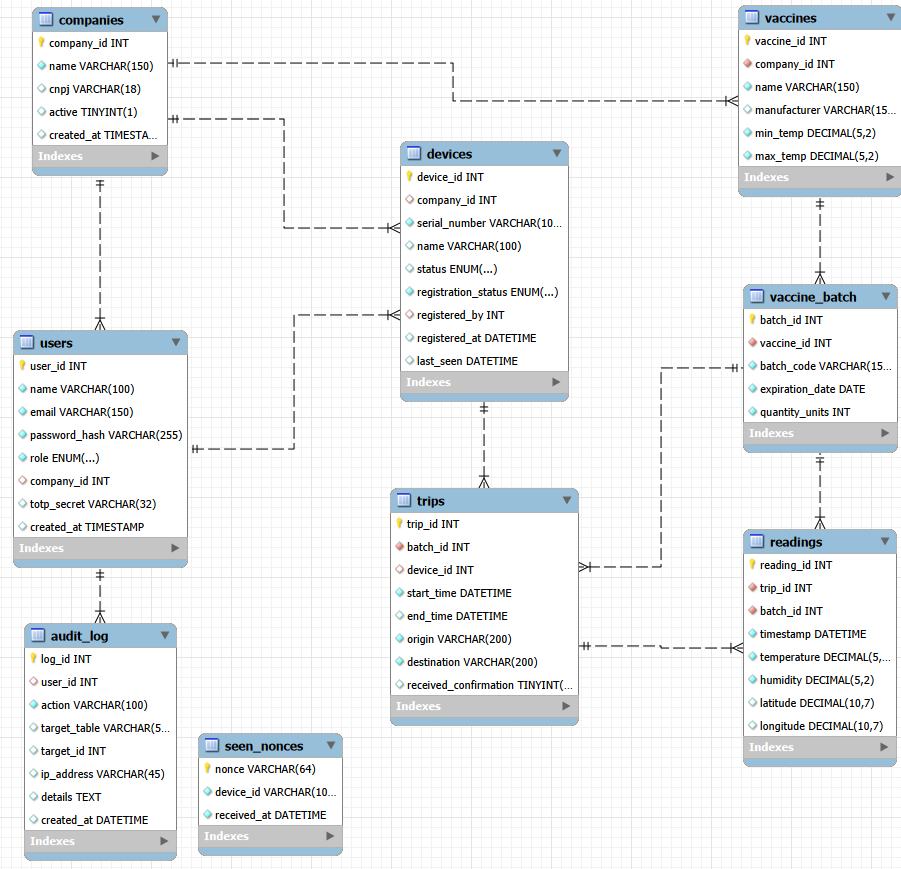
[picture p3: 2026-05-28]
diagrams/TG2/imagems/banco de dados.png

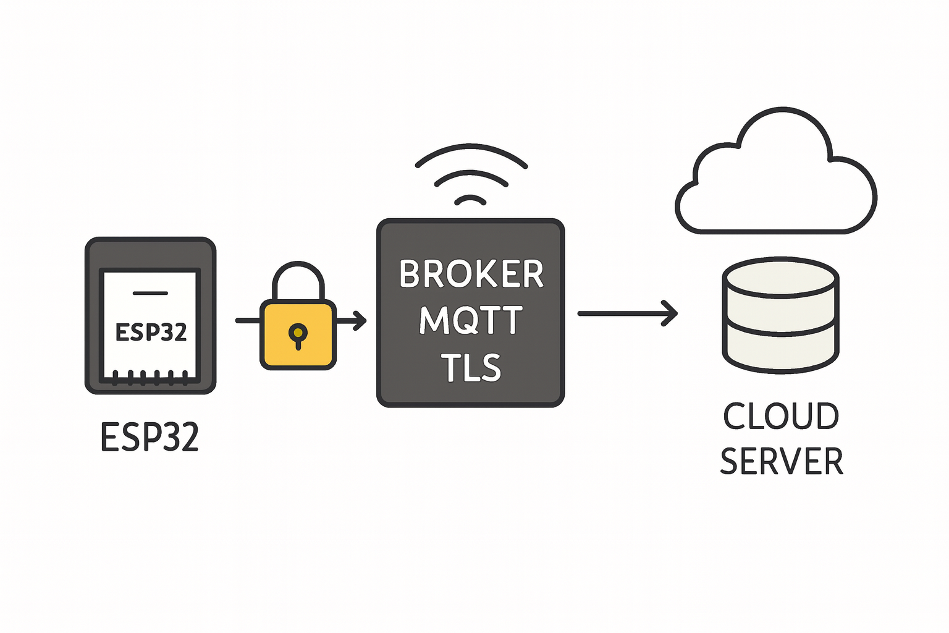
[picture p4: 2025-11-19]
diagrams/conectividade dev.png

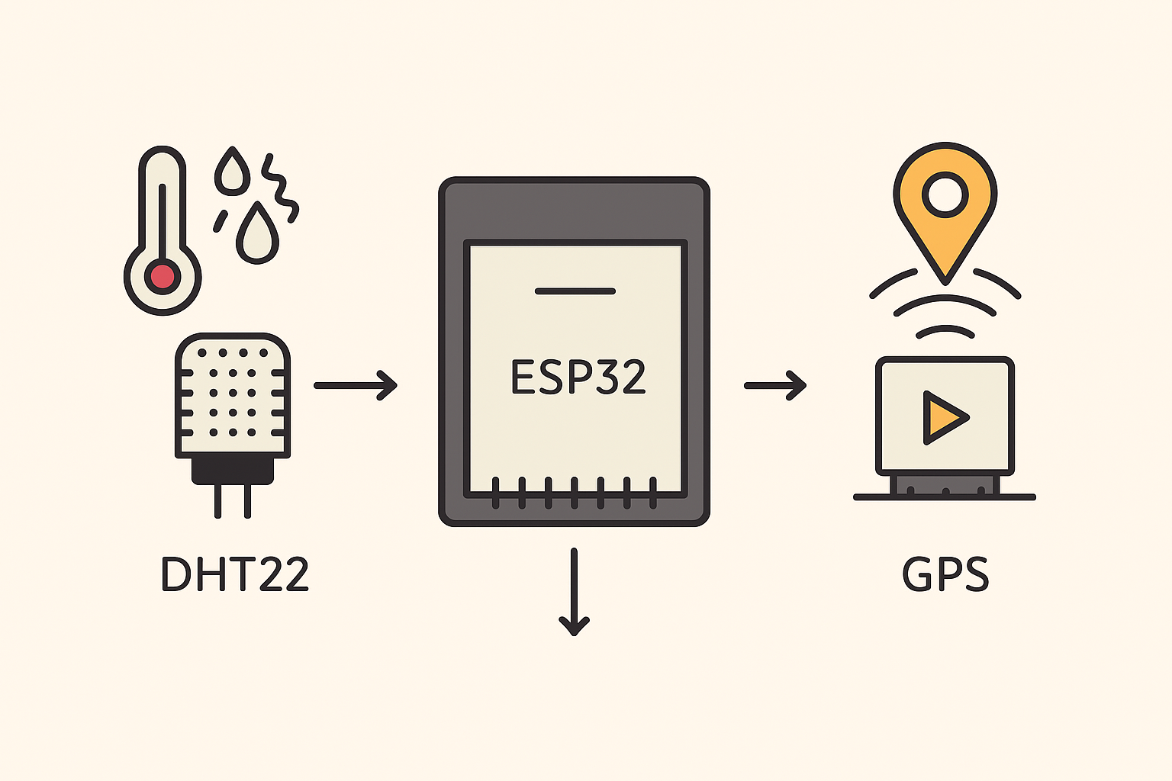
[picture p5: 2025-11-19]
diagrams/Diagrama percepcao.png

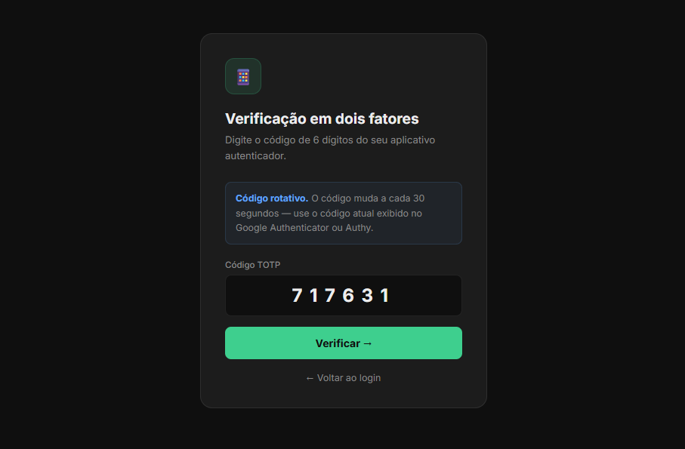
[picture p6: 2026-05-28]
diagrams/TG2/imagems/mfa.png

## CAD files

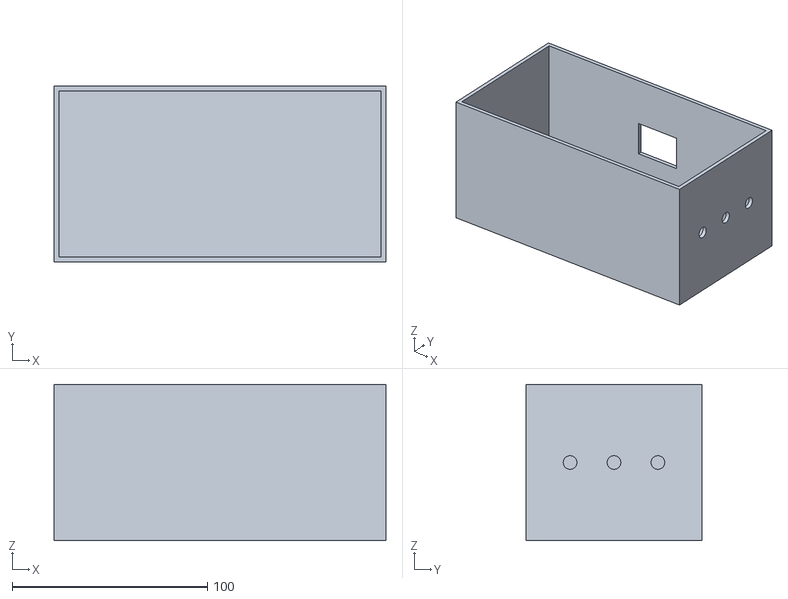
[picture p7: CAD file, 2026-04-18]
hardware/caixa.stl
170.0 x 90.0 x 80.0

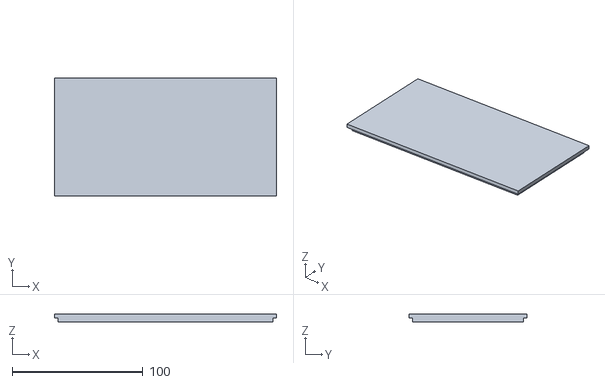
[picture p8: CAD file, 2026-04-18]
hardware/tampa.stl
170.0 x 90.0 x 6.00

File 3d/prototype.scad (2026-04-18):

// --- PARÂMETROS GERAIS (Medidas em mm) ---
largura_proto = 58;      // Largura da protoboard (+ folga leve)
comprimento_proto = 86;  // Comprimento da protoboard (+ folga leve)
altura_interna = 45;     // Altura interna da caixa (ESP32 + fios)

espessura_parede = 2.0;
raio_canto = 3;

// --- PARÂMETROS DOS BURACOS ---

// 1. Configuração do USB (Lateral MENOR - "Frente")
largura_usb = 14;         // Largura do buraco para o conector USB
altura_usb = 10;          // Altura do buraco para o conector USB
altura_do_chao_usb = 6;   // ⚠️ ALTURA DO USB ATÉ O CHÃO INTERNO DA CAIXA (AJUSTE!)

// 2. Configuração do DHT22 (Lateral MAIOR - "Lado Direito")
largura_dht = 18;         // Largura do buraco para o corpo do DHT22 ou seus fios
altura_dht = 26;          // Altura do buraco para o DHT22
distancia_canto_dht = 15; // Distância do canto esquerdo da parede até o buraco do DHT22
altura_do_chao_dht = 10;  // ⚠️ ALTURA DO DHT22 ATÉ O CHÃO INTERNO DA CAIXA (AJUSTE!)

// --- RENDERIZAÇÃO ---

$fn = 60; // Qualidade da curva

dim_x = comprimento_proto + (espessura_parede * 2);
dim_y = largura_proto + (espessura_parede * 2);
dim_z = altura_interna + espessura_parede;

module caixa_arredondada(x, y, z, r) {
    hull() {
        translate([r, r, 0]) cylinder(h=z, r=r);
        translate([x-r, r, 0]) cylinder(h=z, r=r);
        translate([x-r, y-r, 0]) cylinder(h=z, r=r);
        translate([r, y-r, 0]) cylinder(h=z, r=r);
    }
}

difference() {
    // 1. O Bloco Principal
    caixa_arredondada(dim_x, dim_y, dim_z, raio_canto);
    
    // 2. O Oco Interno
    translate([espessura_parede, espessura_parede, espessura_parede])
        caixa_arredondada(comprimento_proto, largura_proto, dim_z + 1, raio_canto/2);
        
    // --- CORTES (Buracos) ---
    
    // A. Buraco USB (Na face frontal - Y=0)
    // Centralizado no eixo X da parede
    translate([(dim_x/2) - (largura_usb/2), -1, espessura_parede + altura_do_chao_usb])
        cube([largura_usb, espessura_parede + 2, altura_usb]);

    // B. Buraco DHT22 (Na lateral direita - X=dim_x)
    // Distância do canto "inferior" da parede Y=0
    translate([dim_x - espessura_parede -2, distancia_canto_dht, espessura_parede + altura_do_chao_dht])
        rotate([0, 90, 0]) // Rotaciona para cortar na face certa
        cube([espessura_parede + 2, altura_dht, largura_dht]);
        
    // C. Ventilação na tampa
    for (i = [10 : 15 : dim_x-10]) {
        for (j = [10 : 15 : dim_y-10]) {
            translate([i, j, dim_z - espessura_parede/2])
                sphere(r=1.5);
        }
    }
}

// --- TAMPA ---
// Renderizada ao lado da caixa para imprimir junto
translate([0, dim_y + 15, 0]) {
    difference() {
        caixa_arredondada(dim_x, dim_y, 2, raio_canto);
        // Rebaixo da tampa para encaixe
        translate([espessura_parede + 0.2, espessura_parede + 0.2, -1])
            caixa_arredondada(comprimento_proto - 0.4, largura_proto - 0.4, 2, raio_canto/2);
    }
    // Borda de encaixe que se projeta na caixa
    translate([espessura_parede + 0.2, espessura_parede + 0.2, 2])
        difference() {
            caixa_arredondada(comprimento_proto - 0.4, largura_proto - 0.4, 3, raio_canto/2);
            translate([1, 1, -1])
                caixa_arredondada(comprimento_proto - 2.4, largura_proto - 2.4, 5, raio_canto/2);
        }
}

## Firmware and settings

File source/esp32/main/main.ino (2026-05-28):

// ============================================================
// Vaccine Transport IoT — Firmware ESP32
// Milestone 2: TLS/SSL + Credenciais MQTT + HMAC + Nonce
// BCP: Hardware Watchdog + Buffer Offline SPIFFS
// ============================================================

#define MQTT_MAX_PACKET_SIZE 1024

#include <WiFi.h>
#include <WiFiClientSecure.h>
#include <PubSubClient.h>
#include <ArduinoJson.h>
#include <DHT.h>
#include <TinyGPS++.h>
#include "mbedtls/md.h"       // HMAC-SHA256
#include "esp_task_wdt.h"     // Hardware Watchdog Timer
#include <SPIFFS.h>           // Buffer offline
#include <time.h>             // NTP — clock de fallback quando GPS sem fix
#include <vector>             //   std::vector para flush do buffer

// Watchdog: reinicia o ESP32 se o loop principal travar por mais de N segundos
#define WDT_TIMEOUT_SEC 60

// Buffer offline: armazena leituras no SPIFFS quando sem conexão
#define BUFFER_FILE      "/buffer.jsonl"
#define BUFFER_TMP_FILE  "/buffer.tmp"
#define BUFFER_MAX_BYTES 102400   // 100 KB ≈ 500 leituras (~40 min a 5s)

// NTP: servidores e flag de sincronização
#define NTP_SERVER1 "pool.ntp.org"
#define NTP_SERVER2 "time.google.com"
bool ntpSynced = false;

// ======== CONFIGURAÇÕES — ALTERE ANTES DE GRAVAR ========
const char* WIFI_SSID     = "iPhone-Gui";
const char* WIFI_PASSWORD = "hash1234";
const char* MQTT_BROKER   = "1fe6e4dc6c3b41d193f6448d1ab84a93.s1.eu.hivemq.cloud";
const int   MQTT_PORT     = 8883;            // TLS

// Credenciais MQTT (devem coincidir com mosquitto/passwd)
const char* MQTT_USER     = "esp32-device";
const char* MQTT_PASS     = "Esp32Mqtt@2026";

// Chave HMAC-SHA256 (32 bytes) — compartilhada com o servidor
// Em produção: armazenar no NVS via Preferences.h
const char* HMAC_KEY      = "v@ccine-hmac-key-2026-xK9mP7qR!";
// =========================================================

// Device ID gerado automaticamente do endereço MAC (preenchido em setup())
// Formato: ESP32-AABBCCDDEEFF  — único por hardware, sem hardcoding
String DEVICE_ID_STR = "ESP32-UNKNOWN";
const char* DEVICE_ID = nullptr;  // aponta para DEVICE_ID_STR.c_str() após setup()

// Tópicos MQTT
const char* TOPIC_READINGS  = "vaccines/readings";
const char* TOPIC_HEARTBEAT = "vaccines/heartbeat";

// Intervalos
const unsigned long PUBLISH_INTERVAL    = 5000;
const unsigned long HEARTBEAT_INTERVAL  = 30000;

// ======== CA CERTIFICATE — ISRG Root X1 (raiz Let's Encrypt, válida até 2035) ========
// Raiz permanente — não muda quando Let's Encrypt rotaciona intermediários (R12, E5, etc.)
static const char CA_CERT[] PROGMEM = R"EOF(
-----BEGIN CERTIFICATE-----
MIIFazCCA1OgAwIBAgIRAIIQz7DSQONZRGPgu2OCiwAwDQYJKoZIhvcNAQELBQAw
TzELMAkGA1UEBhMCVVMxKTAnBgNVBAoTIEludGVybmV0IFNlY3VyaXR5IFJlc2Vh
cmNoIEdyb3VwMRUwEwYDVQQDEwxJU1JHIFJvb3QgWDEwHhcNMTUwNjA0MTEwNDM4
WhcNMzUwNjA0MTEwNDM4WjBPMQswCQYDVQQGEwJVUzEpMCcGA1UEChMgSW50ZXJu
ZXQgU2VjdXJpdHkgUmVzZWFyY2ggR3JvdXAxFTATBgNVBAMTDElTUkcgUm9vdCBY
MTCCAiIwDQYJKoZIhvcNAQEBBQADggIPADCCAgoBggIBAK3oJHP0FDfzm54rVygc
h77ct984kIxuPOZXoHj3dcKi/vVqbvYATyjb3miGbESTtrFj/RQSa78f0uoxmyF+
0TM8ukj13Xnfs7j/EvEhmkvBioZxaUpmZmyPfjxwv60pIgbz5MDmgK7iS4+3mX6U
A5/TR5d8mUgjU+g4rk8Kb4Mu0UlXjIB0ttov0DiNewNwIRt18jA8+o+u3dpjq+sW
T8KOEUt+zwvo/7V3LvSye0rgTBIlDHCNAymg4VMk7BPZ7hm/ELNKjD+Jo2FR3qyH
B5T0Y3HsLuJvW5iB4YlcNHlsdu87kGJ55tukmi8mxdAQ4Q7e2RCOFvu396j3x+UC
B5iPNgiV5+I3lg02dZ77DnKxHZu8A/lJBdiB3QW0KtZB6awBdpUKD9jf1b0SHzUv
KBds0pjBqAlkd25HN7rOrFleaJ1/ctaJxQZBKT5ZPt0m9STJEadao0xAH0ahmbWn
OlFuhjuefXKnEgV4We0+UXgVCwOPjdAvBbI+e0ocS3MFEvzG6uBQE3xDk3SzynTn
jh8BCNAw1FtxNrQHusEwMFxIt4I7mKZ9YIqioymCzLq9gwQbooMDQaHWBfEbwrbw
qHyGO0aoSCqI3Haadr8faqU9GY/rOPNk3sgrDQoo//fb4hVC1CLQJ13hef4Y53CI
rU7m2Ys6xt0nUW7/vGT1M0NPAgMBAAGjQjBAMA4GA1UdDwEB/wQEAwIBBjAPBgNV
HRMBAf8EBTADAQH/MB0GA1UdDgQWBBR5tFnme7bl5AFzgAiIyBpY9umbbjANBgkq
hkiG9w0BAQsFAAOCAgEAVR9YqbyyqFDQDLHYGmkgJykIrGF1XIpu+ILlaS/V9lZL
ubhzEFnTIZd+50xx+7LSYK05qAvqFyFWhfFQDlnrzuBZ6brJFe+GnY+EgPbk6ZGQ
3BebYhtF8GaV0nxvwuo77x/Py9auJ/GpsMiu/X1+mvoiBOv/2X/qkSsisRcOj/KK
NFtY2PwByVS5uCbMiogziUwthDyC3+6WVwW6LLv3xLfHTjuCvjHIInNzktHCgKQ5
ORAzI4JMPJ+GslWYHb4phowim57iaztXOoJwTdwJx4nLCgdNbOhdjsnvzqvHu7Ur
TkXWStAmzOVyyghqpZXjFaH3pO3JLF+l+/+sKAIuvtd7u+Nxe5AW0wdeRlN8NwdC
jNPElpzVmbUq4JUagEiuTDkHzsxHpFKVK7q4+63SM1N95R1NbdWhscdCb+ZAJzVc
oyi3B43njTOQ5yOf+1CceWxG1bQVs5ZufpsMljq4Ui0/1lvh+wjChP4kqKOJ2qxq
4RgqsahDYVvTH9w7jXbyLeiNdd8XM2w9U/t7y0Ff/9yi0GE44Za4rF2LN9d11TPA
mRGunUHBcnWEvgJBQl9nJEiU0Zsnvgc/ubhPgXRR4Xq37Z0j4r7g1SgEEzwxA57d
emyPxgcYxn/eR44/KJ4EBs+lVDR3veyJm+kXQ99b21/+jh5Xos1AnX5iItreGCc=
-----END CERTIFICATE-----
)EOF";
// =================================================================================

// ======== CONFIG DHT22 ========
#define DHTPIN 4
#define DHTTYPE DHT22
DHT dht(DHTPIN, DHTTYPE);

// ======== CONFIG GPS ========
TinyGPSPlus gps;
HardwareSerial SerialGPS(1);
#define GPS_RX_PIN 16
#define GPS_TX_PIN 17
#define GPS_BAUD   9600

// ======== MQTT CLIENT (com TLS) ========
WiFiClientSecure wifiClientSecure;
PubSubClient     mqttClient(wifiClientSecure);

// Controle de tempo e estado de conexão
unsigned long lastPublish   = 0;
unsigned long lastHeartbeat = 0;
bool prevMqttOk = false;   // detecta transição desconectado → conectado


// -------------------------------------------------------
// Gera nonce de 8 bytes em hex usando esp_random()
String generateNonce() {
  char buf[17];
  uint32_t r1 = esp_random();
  uint32_t r2 = esp_random();
  snprintf(buf, sizeof(buf), "%08x%08x", r1, r2);
  return String(buf);
}


// -------------------------------------------------------
// Calcula HMAC-SHA256 de 'data' com HMAC_KEY
// Retorna string hex de 64 chars
String computeHMAC(const String& data) {
  unsigned char hmacResult[32];
  mbedtls_md_context_t ctx;
  mbedtls_md_type_t mdType = MBEDTLS_MD_SHA256;

  mbedtls_md_init(&ctx);
  mbedtls_md_setup(&ctx, mbedtls_md_info_from_type(mdType), 1);
  mbedtls_md_hmac_starts(&ctx,
    (const unsigned char*)HMAC_KEY, strlen(HMAC_KEY));
  mbedtls_md_hmac_update(&ctx,
    (const unsigned char*)data.c_str(), data.length());
  mbedtls_md_hmac_finish(&ctx, hmacResult);
  mbedtls_md_free(&ctx);

  char hexStr[65];
  for (int i = 0; i < 32; i++) {
    snprintf(hexStr + (i * 2), 3, "%02x", hmacResult[i]);
  }
  return String(hexStr);
}


// -------------------------------------------------------
// Tenta conectar ao WiFi (máx. 10s). Retorna true se conectado.
// Não bloqueia indefinidamente — o loop continua mesmo sem WiFi.
bool ensureWiFi() {
  if (WiFi.status() == WL_CONNECTED) return true;

  Serial.printf("[WiFi] Sem conexão. Tentando %s...\n", WIFI_SSID);
  WiFi.disconnect(true);
  WiFi.begin(WIFI_SSID, WIFI_PASSWORD);

  for (int i = 0; i < 10; i++) {
    esp_task_wdt_reset();
    delay(1000);
    if (WiFi.status() == WL_CONNECTED) {
      Serial.printf("[WiFi] Reconectado! IP: %s\n",
                    WiFi.localIP().toString().c_str());
      ntpSynced = false;  // força resync após reconexão
      syncNTP();
      return true;
    }
  }
  Serial.println("[WiFi] Falha. Gravando offline e tentando no proximo ciclo.");
  return false;
}


// -------------------------------------------------------
// Sincroniza clock interno via NTP (máx. 5s).
// Chamado após cada reconexão WiFi — fallback de timestamp quando GPS sem fix.
void syncNTP() {
  if (ntpSynced) return;   // já sincronizado — clock interno continua andando
  configTime(0, 0, NTP_SERVER1, NTP_SERVER2);  // UTC, sem DST
  struct tm t;
  for (int i = 0; i < 10; i++) {
    esp_task_wdt_reset();
    delay(500);
    if (getLocalTime(&t) && t.tm_year > 100) {  // ano > 2000
      ntpSynced = true;
      char buf[25];
      strftime(buf, sizeof(buf), "%Y-%m-%dT%H:%M:%SZ", &t);
      Serial.printf("[NTP] Sincronizado: %s\n", buf);
      return;
    }
  }
  Serial.println("[NTP] Falha na sincronização. Tentando no proximo ciclo.");
}


// -------------------------------------------------------
// Tenta UMA conexão MQTT. Retorna true se conectado.
// Não bloqueia — se falhar, o loop continua e grava no buffer.
bool ensureMQTT() {
  if (mqttClient.connected()) return true;

  Serial.print("[MQTT] Tentando broker...");
  if (mqttClient.connect(DEVICE_ID, MQTT_USER, MQTT_PASS)) {
    Serial.println(" OK");
    return true;
  }
  Serial.printf(" Falha (rc=%d). Gravando offline.\n", mqttClient.state());
  return false;
}


// -------------------------------------------------------
// Salva payload JSON no buffer offline (SPIFFS)
void saveToBuffer(const char* payload) {
  if (SPIFFS.exists(BUFFER_FILE)) {
    File f = SPIFFS.open(BUFFER_FILE, "r");
    if (f && f.size() >= BUFFER_MAX_BYTES) {
      f.close();
      Serial.println("[Buffer] Cheio! Leitura descartada.");
      return;
    }
    if (f) f.close();
  }
  File f = SPIFFS.open(BUFFER_FILE, "a");
  if (!f) {
    Serial.println("[Buffer] Erro ao abrir arquivo!");
    return;
  }
  f.println(payload);
  f.close();
  Serial.println("[Buffer] Leitura salva offline.");
}


// -------------------------------------------------------
// Envia todas as leituras do buffer e remove o arquivo.
// Linhas com falha voltam ao buffer via arquivo temporário.
void flushBuffer() {
  if (!SPIFFS.exists(BUFFER_FILE)) return;

  // Aguarda conexão estabilizar antes de publicar
  delay(300);
  for (int i = 0; i < 3; i++) { mqttClient.loop(); delay(50); }

  if (!mqttClient.connected()) {
    Serial.println("[Buffer] Conexao perdeu antes do flush. Adiando.");
    return;
  }

  File src = SPIFFS.open(BUFFER_FILE, "r");
  if (!src) { Serial.println("[Buffer] Erro ao abrir buffer para leitura."); return; }

  size_t fileSize = src.size();
  Serial.printf("[Buffer] Iniciando flush — %u bytes no buffer.\n", fileSize);

  // Coleta todas as linhas em memória antes de apagar o arquivo
  std::vector<String> lines;
  while (src.available()) {
    String line = src.readStringUntil('\n');
    line.trim();
    if (line.length() > 0) lines.push_back(line);
  }
  src.close();
  SPIFFS.remove(BUFFER_FILE);  // apaga agora — reescreve só o que falhar

  Serial.printf("[Buffer] %d leituras para enviar.\n", (int)lines.size());

  int published = 0;
  std::vector<String> failed;

  for (auto& line : lines) {
    esp_task_wdt_reset();
    mqttClient.loop();

    if (!mqttClient.connected()) {
      Serial.println("[Buffer] Conexao caiu durante flush. Salvando restantes.");
      failed.push_back(line);
      // adiciona as restantes também
      for (size_t j = &line - &lines[0] + 1; j < lines.size(); j++)
        failed.push_back(lines[j]);
      break;
    }

    bool ok = mqttClient.publish(TOPIC_READINGS, line.c_str(), true);
    Serial.printf("[Buffer] Linha %d/%d: %s\n",
                  published + (int)failed.size() + 1, (int)lines.size(),
                  ok ? "OK" : "FALHOU");
    if (ok) {
      published++;
      mqttClient.loop();
      delay(150);
    } else {
      failed.push_back(line);
    }
  }

  // Salva de volta as que falharam
  if (!failed.empty()) {
    File f = SPIFFS.open(BUFFER_FILE, "w");
    if (f) {
      for (auto& l : failed) f.println(l);
      f.close();
    }
    Serial.printf("[Buffer] Flush parcial: %d enviados, %d pendentes\n",
                  published, (int)failed.size());
  } else {
    Serial.printf("[Buffer] Flush completo: %d leituras enviadas\n", published);
  }
}


// -------------------------------------------------------
// Prioridade: GPS (mais preciso) → NTP (fallback) → vazio (Flask usa NOW())
String buildTimestamp() {
  // 1. GPS com fix válido
  if (gps.date.isValid() && gps.time.isValid() && gps.date.year() > 2000) {
    char buf[25];
    snprintf(buf, sizeof(buf), "%04d-%02d-%02dT%02d:%02d:%02dZ",
             gps.date.year(), gps.date.month(), gps.date.day(),
             gps.time.hour(), gps.time.minute(), gps.time.second());
    return String(buf);
  }
  // 2. NTP sincronizado — clock interno do ESP continua andando mesmo offline
  if (ntpSynced) {
    struct tm t;
    if (getLocalTime(&t) && t.tm_year > 100) {
      char buf[25];
      strftime(buf, sizeof(buf), "%Y-%m-%dT%H:%M:%SZ", &t);
      return String(buf);
    }
  }
  // 3. Sem fonte de tempo — Flask normalizará para NOW()
  return "";
}


// -------------------------------------------------------
// Monta o payload JSON com HMAC-SHA256 e nonce
// Estrutura: { campos... , nonce, hmac }
// O Flask verifica: hmac = HMAC-SHA256(key, payload_sem_hmac)
void buildPayload(float temp, float hum, char* buf, size_t bufLen) {
  StaticJsonDocument<768> doc;
  doc["device_id"]   = DEVICE_ID;
  doc["timestamp"]   = buildTimestamp();
  doc["temperature"] = isnan(temp) ? (float)0.0 : temp;
  doc["humidity"]    = isnan(hum)  ? (float)0.0 : hum;
  if (gps.location.isValid()) {
    doc["latitude"]   = gps.location.lat();
    doc["longitude"]  = gps.location.lng();
    doc["satellites"] = gps.satellites.isValid() ? (int)gps.satellites.value() : 0;
  } else {
    doc["latitude"]   = (float)0.0;
    doc["longitude"]  = (float)0.0;
    doc["satellites"] = 0;
  }

  // Nonce único por mensagem (anti-replay)
  doc["nonce"] = generateNonce();

  // Serializa sem hmac — este texto exato é o que será assinado e enviado no campo "signed"
  char toSign[768];
  serializeJson(doc, toSign, sizeof(toSign));

  // Inclui o texto assinado e o HMAC no payload final
  // Flask usa "signed" para recomputar e comparar com "hmac"
  doc["signed"] = toSign;
  doc["hmac"]   = computeHMAC(String(toSign));

  serializeJson(doc, buf, bufLen);
}


// -------------------------------------------------------
// Publica payload via MQTT — retorna true se sucesso
bool publishReading(const char* payload) {
  if (mqttClient.publish(TOPIC_READINGS, payload, true)) {
    Serial.print("[MQTT] Publicado: ");
    Serial.println(payload);
    return true;
  }
  Serial.println("[MQTT] Falha ao publicar!");
  return false;
}

  
// -------------------------------------------------------
void publishHeartbeat() {
  StaticJsonDocument<128> doc;
  doc["device_id"] = DEVICE_ID;
  doc["timestamp"] = buildTimestamp();
  doc["status"]    = "online";

  char payload[128];
  serializeJson(doc, payload, sizeof(payload));
  mqttClient.publish(TOPIC_HEARTBEAT, payload);
  Serial.println("[MQTT] Heartbeat enviado.");
}


// -------------------------------------------------------
void setup() {
  Serial.begin(115200);
  delay(1000);
  Serial.println("\n=== Vaccine Transport IoT M2 — Iniciando ===");

  // Inicializa hardware watchdog — reinicia o ESP32 se o loop travar
  // API IDF 5.x: recebe esp_task_wdt_config_t em vez de (timeout, panic)
  esp_task_wdt_deinit();  // garante estado limpo antes de configurar
  const esp_task_wdt_config_t wdt_config = {
    .timeout_ms     = WDT_TIMEOUT_SEC * 1000,
    .idle_core_mask = 0,      // não monitora idle tasks
    .trigger_panic  = true,   // reinicia o ESP32 ao disparar
  };
  esp_task_wdt_init(&wdt_config);
  esp_task_wdt_add(NULL);     // monitora a task atual (loop)
  Serial.printf("[WDT] Watchdog ativo — timeout: %ds\n", WDT_TIMEOUT_SEC);

  // Inicializa SPIFFS para buffer offline
  if (!SPIFFS.begin(true)) {
    Serial.println("[SPIFFS] Falha ao montar! Buffer offline indisponivel.");
  } else {
    size_t used  = SPIFFS.usedBytes();
    size_t total = SPIFFS.totalBytes();
    Serial.printf("[SPIFFS] Montado — %u KB usados / %u KB totais\n",
                  used / 1024, total / 1024);
    if (SPIFFS.exists(BUFFER_FILE)) {
      File f = SPIFFS.open(BUFFER_FILE, "r");
      Serial.printf("[SPIFFS] Buffer offline encontrado (%u bytes) — sera enviado ao conectar\n",
                    f ? (unsigned)f.size() : 0);
      if (f) f.close();
    }
  }

  dht.begin();
  SerialGPS.begin(GPS_BAUD, SERIAL_8N1, GPS_RX_PIN, GPS_TX_PIN);

  // Conecta WiFi no boot — tenta até 10s; se falhar, o loop tratará
  ensureWiFi();
  syncNTP();  // sincroniza clock logo no boot

  // Gerar device ID único a partir do MAC address
  // Formato: ESP32-AABBCCDDEEFF — sem hardcoding, único por hardware
  String mac = WiFi.macAddress();   // "AA:BB:CC:DD:EE:FF"
  mac.replace(":", "");             // "AABBCCDDEEFF"
  DEVICE_ID_STR = "ESP32-" + mac;
  DEVICE_ID = DEVICE_ID_STR.c_str();
  Serial.print("[Device] ID: ");
  Serial.println(DEVICE_ID);

  // TLS ativo (tráfego cifrado) — validação de cert desabilitada
  // Nota: ESP32 mbedtls tem incompatibilidade com cadeia ISRG Root X1 do HiveMQ Cloud
  wifiClientSecure.setInsecure();

  mqttClient.setBufferSize(768);
  mqttClient.setServer(MQTT_BROKER, MQTT_PORT);

  Serial.println("=== Sistema pronto (TLS ativo) ===\n");
}


// -------------------------------------------------------
void loop() {
  esp_task_wdt_reset();   // alimenta o watchdog — prova que o loop está vivo

  while (SerialGPS.available() > 0) {
    gps.encode(SerialGPS.read());
  }

  // Verifica conectividade — não bloqueante; falha → grava no buffer
  bool wifiOk = ensureWiFi();
  bool mqttOk = wifiOk && ensureMQTT();

  if (mqttOk) {
    mqttClient.loop();
    // Flush só quando acaba de reconectar (transição false → true)
    if (!prevMqttOk) {
      Serial.println("[MQTT] Reconectado! Aguardando subscribers reconectarem (5s)...");
      // QoS 0: broker não guarda mensagens. Aguardamos o Flask resubscrever
      // antes de publicar o buffer, senão as mensagens são perdidas.
      for (int i = 0; i < 50; i++) {
        esp_task_wdt_reset(); 
        mqttClient.loop();
        delay(100);
      }
      Serial.println("[MQTT] Verificando buffer offline...");
      flushBuffer();
    }
  }
  prevMqttOk = mqttOk;

  unsigned long now = millis();

  if (now - lastPublish >= PUBLISH_INTERVAL) {
    lastPublish = now;

    float hum  = dht.readHumidity();
    float temp = dht.readTemperature();

    if (isnan(hum) || isnan(temp)) {
      Serial.println("[DHT22] Falha na leitura!");
    } else {
      Serial.printf("[DHT22] Temp: %.1f°C | Umidade: %.1f%%\n", temp, hum);
    }

    if (gps.location.isValid()) {
      Serial.printf("[GPS] Lat: %.6f | Lng: %.6f | Sats: %d\n",
                    gps.location.lat(), gps.location.lng(),
                    gps.satellites.isValid() ? (int)gps.satellites.value() : 0);
    } else {
      Serial.println("[GPS] Aguardando fix...");
    }

    // Monta payload uma única vez — usado tanto para publish como para buffer
    char payload[1024];
    buildPayload(temp, hum, payload, sizeof(payload));

    if (mqttOk) {
      if (!publishReading(payload)) {
        saveToBuffer(payload);  // publish falhou → guarda localmente
      }
    } else {
      saveToBuffer(payload);    // sem conexão → guarda localmente
      Serial.println("[Modo offline] Leitura armazenada no SPIFFS.");
    }
  }

  if (now - lastHeartbeat >= HEARTBEAT_INTERVAL) {
    lastHeartbeat = now;
    if (mqttOk) publishHeartbeat();
  }
}

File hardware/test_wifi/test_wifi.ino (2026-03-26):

#include <WiFi.h>

const char* ssid = "iPhone-Gui";
const char* password = "hash1234";

void printStatus(int status) {
  Serial.print("Status WiFi: ");
  Serial.print(status);
  Serial.print(" -> ");

  switch (status) {
    case WL_IDLE_STATUS: Serial.println("IDLE"); break;
    case WL_NO_SSID_AVAIL: Serial.println("SSID NAO ENCONTRADO"); break;
    case WL_SCAN_COMPLETED: Serial.println("SCAN COMPLETO"); break;
    case WL_CONNECTED: Serial.println("CONECTADO"); break;
    case WL_CONNECT_FAILED: Serial.println("FALHA NA CONEXAO"); break;
    case WL_CONNECTION_LOST: Serial.println("CONEXAO PERDIDA"); break;
    case WL_DISCONNECTED: Serial.println("DESCONECTADO"); break;
    default: Serial.println("DESCONHECIDO"); break;
  }
}

void setup() {
  Serial.begin(115200);
  delay(2000);

  Serial.println("\n=== DEBUG WIFI ESP32 ===\n");

  // Reset WiFi
  WiFi.disconnect(true);
  delay(1000);
  WiFi.mode(WIFI_STA);

  // 🔍 Scan redes
  Serial.println("Escaneando redes...");
  int n = WiFi.scanNetworks();

  if (n == 0) {
    Serial.println("Nenhuma rede encontrada");
  } else {
    Serial.println("Redes encontradas:");
    for (int i = 0; i < n; ++i) {
      Serial.print("- ");
      Serial.print(WiFi.SSID(i));
      Serial.print(" | RSSI: ");
      Serial.print(WiFi.RSSI(i));
      Serial.print(" | Seguranca: ");
      Serial.println(WiFi.encryptionType(i));
    }
  }

  Serial.println("\nTentando conectar...\n");

  // 🔌 Conexão
  WiFi.begin(ssid, password);

  int tentativas = 0;

  while (WiFi.status() != WL_CONNECTED && tentativas < 20) {
    printStatus(WiFi.status());
    delay(1000);
    tentativas++;
  }

  Serial.println("\n=== RESULTADO ===");

  if (WiFi.status() == WL_CONNECTED) {
    Serial.println("✅ CONECTADO COM SUCESSO!");
    Serial.print("IP: ");
    Serial.println(WiFi.localIP());
  } else {
    Serial.println("❌ NAO CONECTOU");
    printStatus(WiFi.status());
  }
}

void loop() {}

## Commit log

2025-11-29 Final version of the document sent, and fisrt version of the prototype
    [prototype.scad]
2026-03-16 Dashboard with better visuals and MFA, ESP32 main code working, but new update CA+TLS to be tested
2026-03-16 connection between ESP32 and MQTT with TLS working + MFA on the app + new design
2026-03-16 security: remove exposed private keys and regenerate certificates
    - Remove certs/backup_4096/ (contained ca.key and broker.key exposed on GitHub)
    - Strengthen .gitignore: block all *.key and *.pem recursively, block certs/ dir
    - Regenerate CA (2048-bit) and broker cert with new key pair
    - Update ESP32 firmware with new CA cert
    - Rotate certs after key compromise per security best practices
    [main.ino]
2026-03-20 code to 3d completed and gps fully operating
    [caixa.stl, caixinha.scad, tampa.stl]
2026-04-18 system operating with new CA to conect to broker after flaw
    [caixa.stl, caixinha.scad, prototype.scad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]
2026-04-19 Configure ESP32 flow improved and working
2026-04-19 Temperature chart improved
2026-06-19 system fully operating. this commit is a backup state for the futere updates to the temperature chart
2026-08-01 Revise README to highlight IoT cold chain monitoring
    Updated project description to focus on IoT-based pharmaceutical cold chain monitoring system features and technologies used.
